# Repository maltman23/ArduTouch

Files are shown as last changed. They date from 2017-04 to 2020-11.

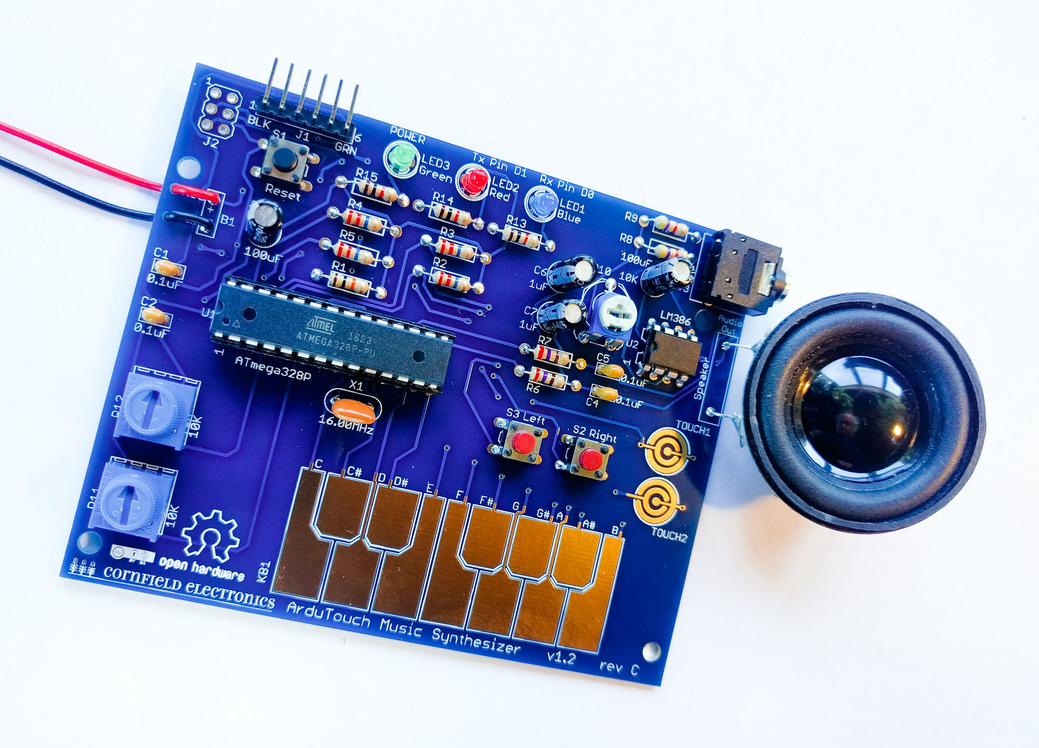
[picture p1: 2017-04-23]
Photo/ArduTouch.jpg

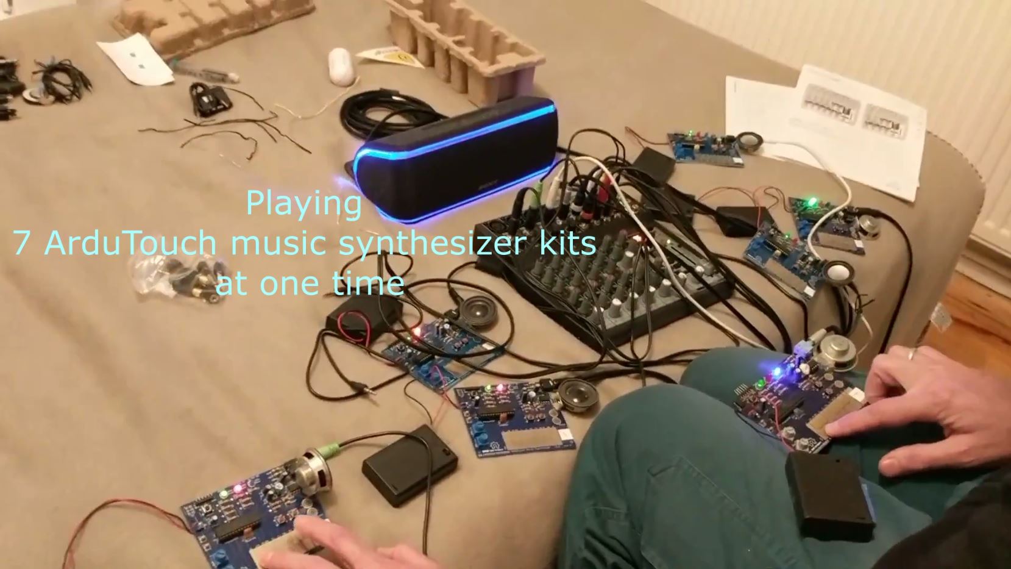
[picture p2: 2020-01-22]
Demo videos/7 at Once/7 ArduTouch at Once thumb.JPG

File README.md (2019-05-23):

# ArduTouch
photo of ArduTouch
ArduTouch is an Arduino-compatible music synthesizer kit.  
Build it, and it works!  
Way low cost (currently $30.)  
It comes with a pre-programmed music synthesizer that makes way cool sounds and music and noise.

An ArduTouch library is available for programming in more super nice synthesizer features, and for making your own synthesizers.
The library comes with examples (with more to come) that serve as a nice tutorial on how to create your own ArduTouch synthesizers (which are Arduino sketches).

ArduTouch is really just an Arduino Uno clone with a small amplifier & speaker, with a PCB touch keyboard, a couple of extra buttons, and a couple of pots (for playing music and controlling the sounds).  The ArduTouch Arduino Library is where the real magic comes from!

For those who want to learn more, the documentation teaches the basics of Digital Signal Processing for audio generation (more documentation coming soon).

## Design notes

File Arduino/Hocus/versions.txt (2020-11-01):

Versions:

   1.00  use embedded U/I frames 
         _Sn2345 not available if CONSOLE_OUTPUT
         syncs with library 1.16
   0.99  === FIRST PUBLISHED VERSION ===

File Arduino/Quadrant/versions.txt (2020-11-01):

Versions:

   1.73  use embedded U/I frames 
         syncs with library 1.16
   1.72  bugfix: upper bound condition in LED iteration corrected to "< NUMLEDs" from "<= NumLEDs"
         [31722] _STNDLONE_ lib 1.15 Build 1.6.6
   1.71  newOsc() returns NULL (instead of new Osc())
   1.70  nix BUILD_166 conditional compilation sections
   1.69  add FRAME21 pots to control lead 1 detune and transpose
         [31742] _STNDLONE_ BUILD_166
   1.68  edit presets/macros to use byte values <= 128 when setting LFO depths 
         syncs with library 1.13
         [31684] _STNDLONE_ BUILD_166
   1.67  === FIRST PUBLISHED VERSION ===

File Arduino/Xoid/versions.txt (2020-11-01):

Versions:

   0.98  use embedded U/I frames 
         syncs with library 1.16
   0.97  edit presets to use byte values <= 128 when setting LFO depths 
         syncs with library 1.13
   0.96  quiet preset loading
   0.95  resident Gain amplitude modifier is replaced by library's Gain effect
         syncs with 1.10
   0.94  Synth::setup() renamed ::config() to circumvent Arduino bug
         syncs with 1.10
   0.93  set_baud_rate() nixed
         normal blink rate
         syncs with 1.08
   0.92  === FIRST PUBLISHED VERSION ===

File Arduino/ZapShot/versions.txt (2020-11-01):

Versions:

   1.34  statusLED logic is rewritten
   1.33  ZapShotSynth::forEach() migrated to library as VoxSynth::forEach()
         syncs with library 1.15
   1.32  bugfix: autotrig LED must be refreshed on reset
   1.31  edit presets to use byte values <= 128 when setting LFO depths 
         syncs with library 1.13
   1.30  Synth::setup() renamed ::config() to circumvent Arduino bug
         syncs with 1.10
   1.29  === FIRST PUBLISHED VERSION ===

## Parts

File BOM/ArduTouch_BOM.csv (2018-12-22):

Qty | Designator | Description | Jameco | Mouser | mfg | mfg part # | mfg | mfg part #
1 | B1 | 3xAA battery holder w/ leads, w/ switch | 216144 | 854-PW3AA | Jameco | SBH-331-AS-R | BusBoard | PW-3AA
4 | C1, C2, C4, C5 | 0.1uF, 50V, ceramic, 0.1" spacing leads |  | 594-K104K15X7RF53L2 | Vishay / BC Components | K104K15X7RF53L2
2 | C3, C8 | 100uF, 16V or higher, electrolytic, radial, 0.1" spacing leads |  | 598-107CKS016M | Cornell Dubilier - CDE | 107CKS016M
2 | C6, C7 | 1uF, 16V or higher, electrolytic, radial, 0.1" spacing leads |  | 598-105CKR050M | Illinois Capacitor / CDE | 105CKR050M
1 | J1 | 1x6, right-angle (FTDI) |  | 649-68016-106HLF | FCI | 68016-106HLF
0 | J2 | not used
1 | J3 | headphone, stereo, 3.5mm, switched |  | 806-STX-31205B284C | Kycon | STX-3120-5B-284C
1 | LED1 | Blue LED, 5mm |  | 941-C5SMFBJFCR0U0351 | Cree | C5SMF-BJF-CR0U0351
1 | LED2 | Red LED, 5mm |  | 941-C5SMFRJFCT0W0BB1 | Cree | C5SMF-RJF-CT0W0BB1
1 | LED3 | Green LED, 5mm |  | 941-C5SMFGJFCV0Y0791 | Cree | C5SMF-GJF-CV0Y0791
1 | R1 | 10K, 1/4W, 5% | 691104 | 71CCF0710K0JKE36 | Jameco | CF1/4W103JRC | Vishay | CCF0710K0JKE36
4 | R2, R3, R4, R5 | 22M, 1/4W, 5% |  | 660-CF1/4C226J | KOA Speer | CF1/4C226J
2 | R6, R7 | 270, 1/4W, 5% | 690726 | 588-OD271JE | Jameco | CF1/4W271JRC | Ohmite | OD271JE
2 | R8, R9 | 4.7K, 1/4W, 5% | 691024 | 71-CCF07J4.7KE3 | Jameco | CF1/4W472JRC | Vishay | CCF074K70JKE36
1 | R10 | 10K trim pot (screwdriver adjust - Volume) |  | 652-3319P-1-103 | Bourns | 3319P-1-103
2 | R11, R12 | 10K trim pot (knob adjust) |  | 858-72PTR10KLF | BI Technologies / TT Electronics | 72PTR10KLF
3 | R13, R14, R15 | 1K, 1/4W, 5% | 690865 | 71-CCF071K00JKE36 | Jameco | CF1/4W102JRC | Vishay | CCF071K00JKE36
1 | S1 | SPST tact switch, 4-pin, Black button (Reset) |  | 688-SKHHAK | ALPS | SKHHAKA010
2 | S2, S3 | SPST tact switch, 4-pin, Red button |  | 688-SKHHAQ | ALPS | SKHHAQA010
1 | SPKR1 | 40mm diameter speaker, 3W, 4 Ohm |  | 665-AS04004PR-R | PUI Audio | AS04004PR-R
1 | U1 | ATmega328P-PU |  | 556-ATMEGA328P-PU | Atmel | ATMEGA328P-PU
1 | U2 | NJM386BD |  | 513-NJM386BD | NJR | NJM386BD
1 | X1 | 16.0MHz ceramic resonator |  | 81-CSTLS16M0X55Z-A0 | Murata Electronics | CSTLS16M0X55Z-A0
1 | PCB | PCB
1 | U1 socket | 28-pin DIP socket | 112299 | 81CSTLS16M0X55ZA0 | Jameco | 6000-28NDW | TE Connectivity | 1-2199298-9
0 | U2 socket | not used (U2 is soldered directly to PCB)
1 | small bag | 7x10cm reclosable plastic bag |  |  | Aliexpress
1 | large bag | 15x22cm reclosable plastic bag |  |  | Aliexpress
1 | label

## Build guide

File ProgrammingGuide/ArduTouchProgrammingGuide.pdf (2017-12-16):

# ArduTouch Music Synthesizer

## Programming Guide

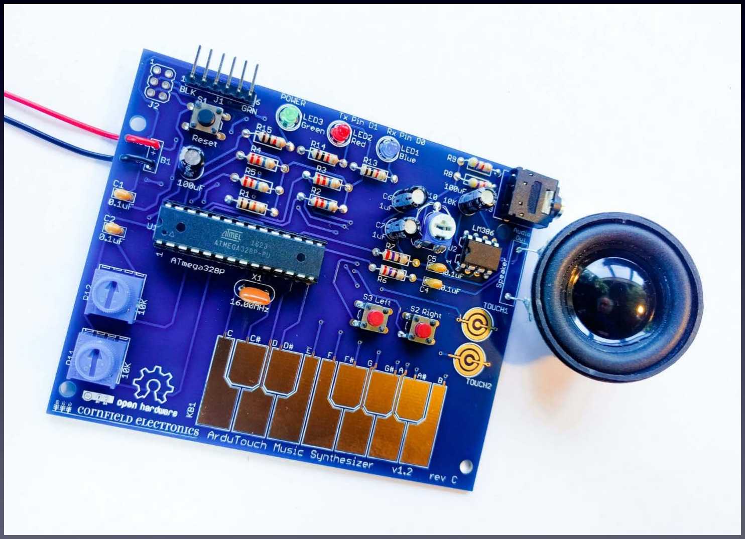
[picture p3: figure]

## rev C

15-Dec-2017

# Let’s make noise!

Your ArduTouch comes pre-programmed with a really cool synthesizer, called “Thick”.

“Thick” plays 4 sawtooth waves at once.
- the left and right buttons change octaves
- long press the left and right buttons to change sounds
- the Bottom knob controls the glide rate
- the Top knob controls how each of the 4 notes glide separately
- Try playing with these and see!

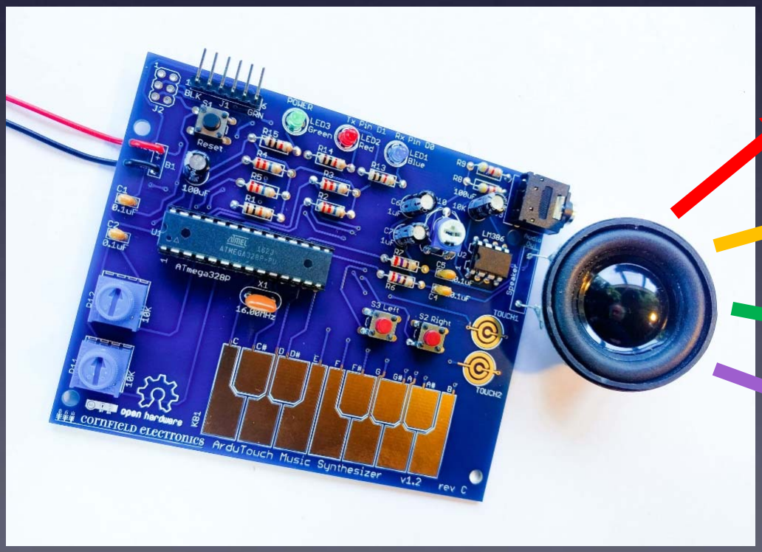
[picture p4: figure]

# Let’s make noise!

Your ArduTouch comes pre-programmed with a really cool synthesizer, called “Thick”.

If you are happy playing with “Thick” then no need to re-program your ArduTouch.

But if you want to
program other synths into your ArduTouch,
the next pages show you how…

# Re-programming the ArduTouch

We have written several way cool synthesizers for ArduTouch! Each is unique, and each way different than the others.

To program in a new synth in your ArduTouch, you will need:
- the Arduino software <http://arduino.cc>
- a USB-Serial adapter cable (such as an FTDI, or equivalent)
- a synth sketch and the ArduTouch Arduino library <http://cornfieldelectronics.com/cfe/projects.php#ardutouch>

# Arduino

Arduino is a very powerful tool! But it is very easy to use. It was designed for total beginners to use successfully.

I won’t give a complete tutorial here – just some basics.
For more info, there are many good Arduino tutorials online. A good place to start is:
<https://www.arduino.cc/en/Tutorial/HomePage>

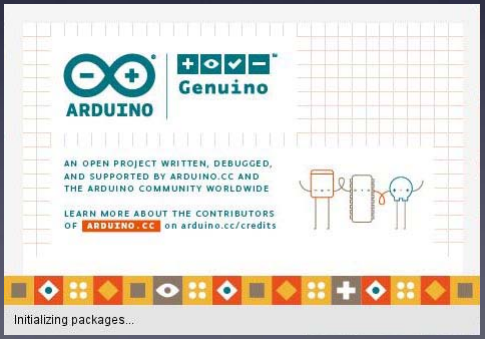
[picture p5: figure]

# Arduino

First:
Download and install the Arduino software < http://arduino.cc >

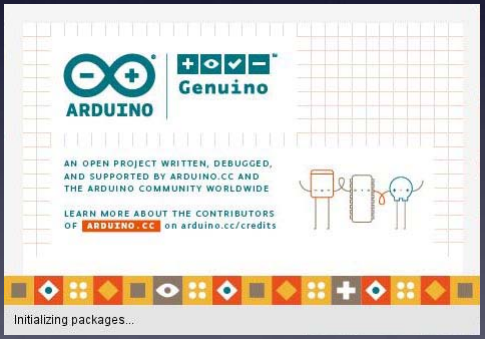
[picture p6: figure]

# Re-programming the ArduTouch

Second:
Download and install the ArduTouch Arduino library <http://cornfieldelectronics.com/cfe/projects.php#ardutouch>

Instructions for installing a .zip library are at: < https://www.arduino.cc/en/Guide/Libraries>
Scroll down till you see the section: “Importing a .zip Library“

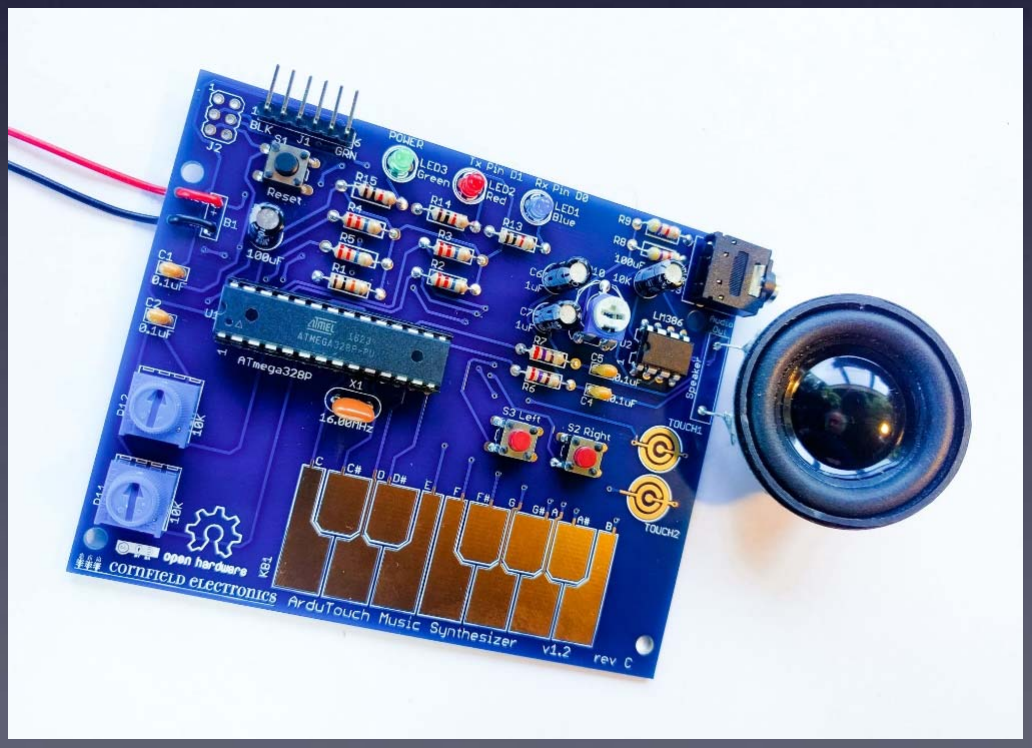
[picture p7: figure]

# Re-programming the ArduTouch

Third:
Download ArduTouch synth sketches <http://cornfieldelectronics.com/cfe/projects.php#ardutouch>

Store them on your computer anywhere you like.

Ones I have available look something like this:

# Connecting your ArduTouch to your computer

USB-Serial adapter cable

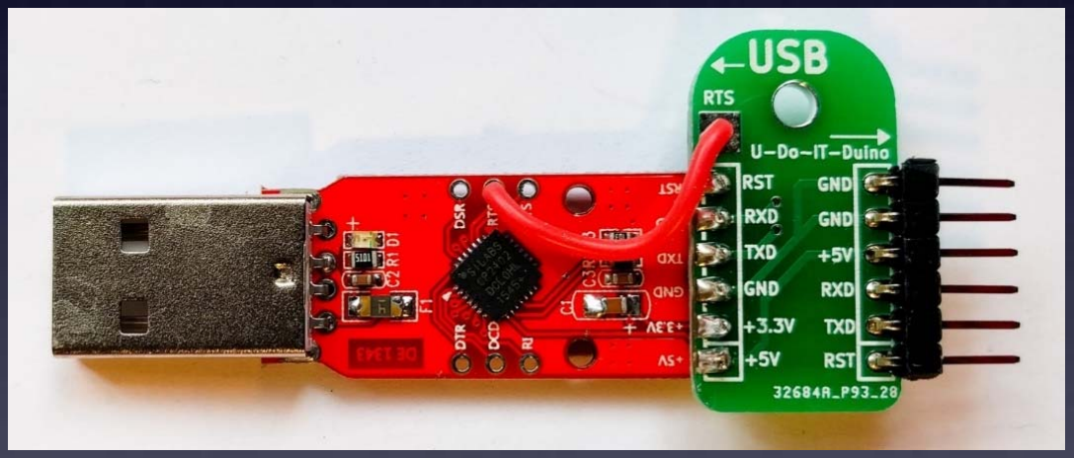
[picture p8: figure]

# Connecting your ArduTouch to your computer

USB-Serial adapter cable

Ones I have available look something like this:

You will need to download and install a driver
for your Operating System (Windows, MacOS, or Linux):

<https://www.silabs.com/products/development-tools/software/usb-to-uart-bridge-vcp-drivers>

# Connecting your ArduTouch to your computer

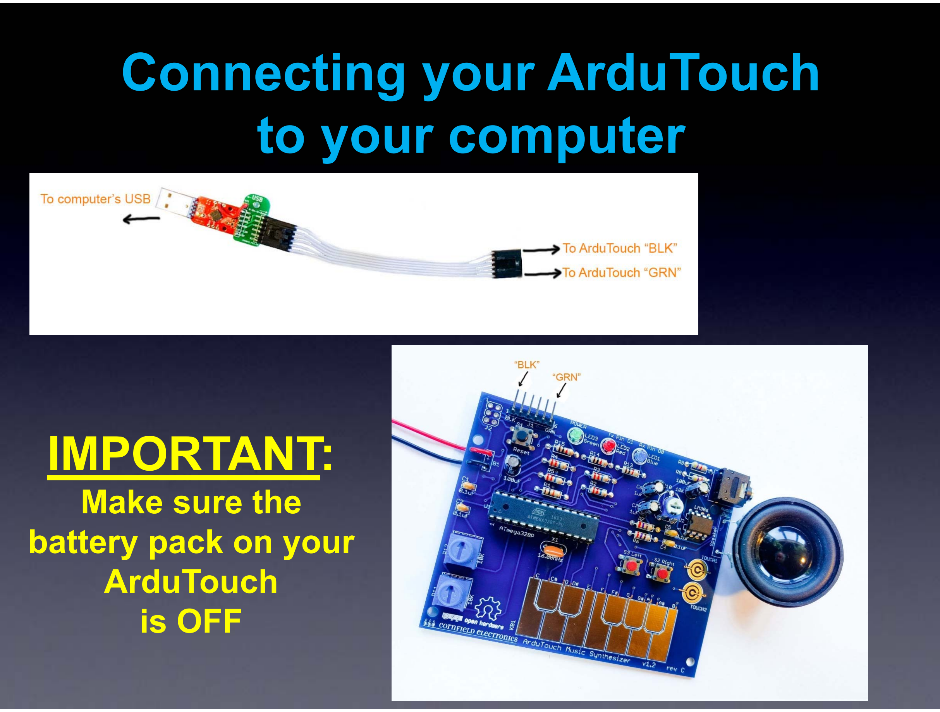
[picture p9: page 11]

# IMPORTANT:

## Make sure the battery pack on your ArduTouch is OFF

# Arduino

After you download and install the Arduino software start it, and you will see a screen that looks like this:

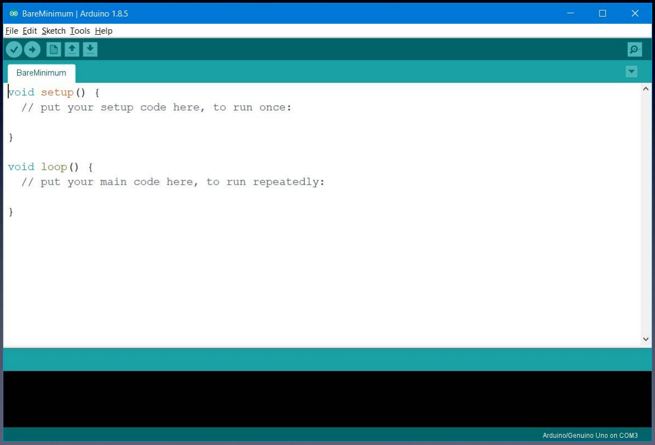
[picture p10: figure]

# Arduino

The first time you start your Arduino software you need to do two things to set things up

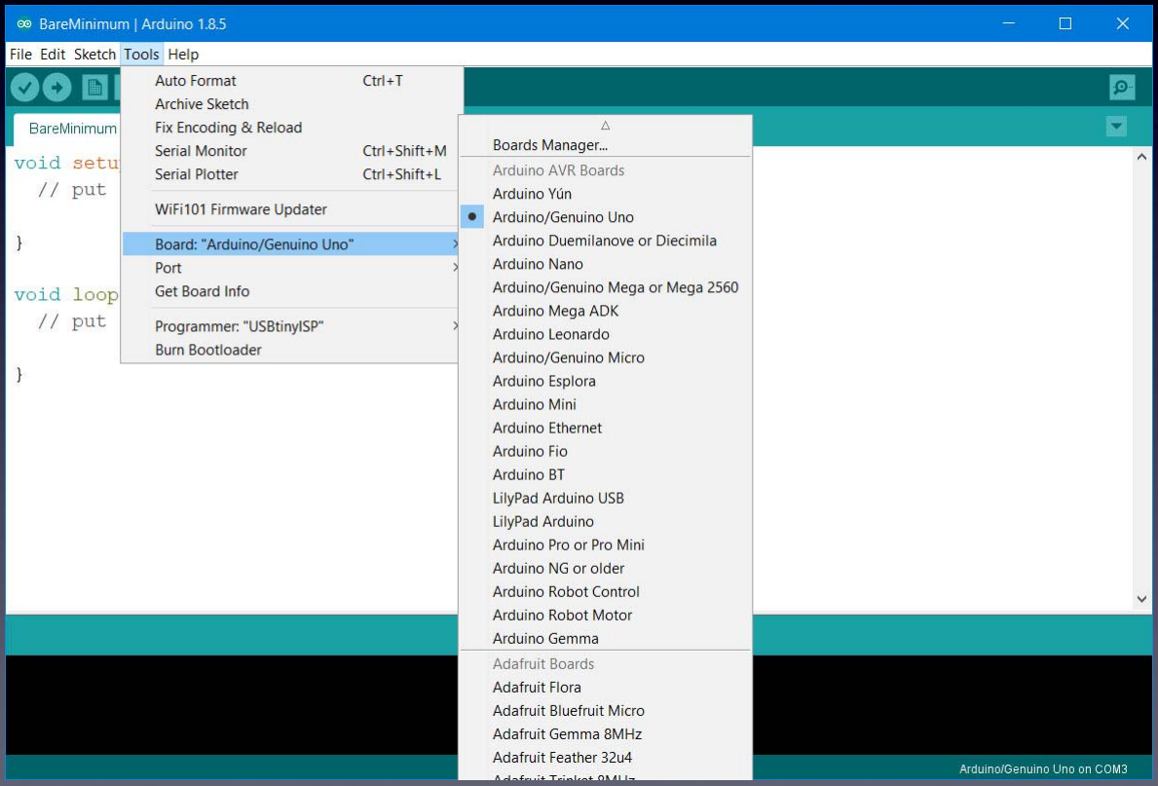
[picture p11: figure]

(1)
Choose “Uno”
as the Board

(Your
ArduTouch board
acts
just like
an
Arduino Uno board)

# Arduino

The first time you start your Arduino software you need to do two things to set things up

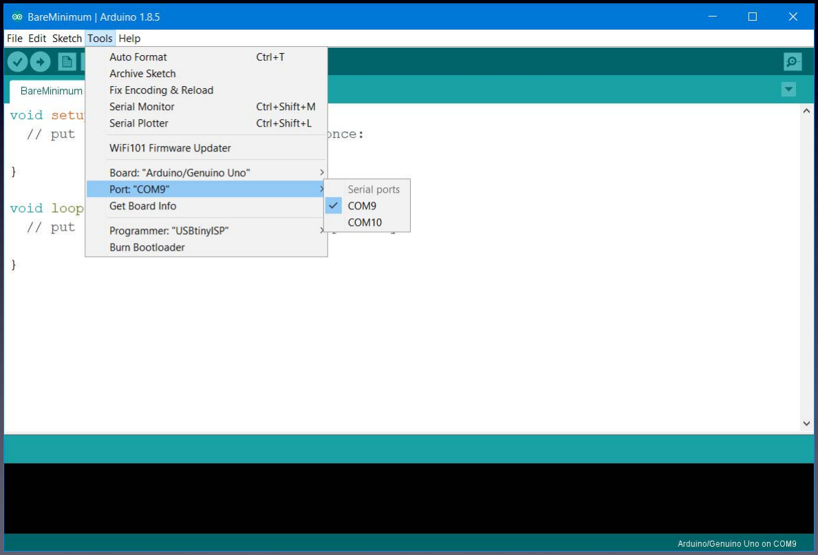
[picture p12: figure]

(2)
Choose
the Port
(this will be
different
depending on
your Operating
System)

(After installing
the driver
for your USB-Serial
cable
your operating system
will see a serial port
and it appears here.)

# Arduino

Your Arduino software is now ready to program your ArduTouch!

# Arduino

You can open an ArduTouch synth sketch from: File → Open…
(I opened “Arpology here)

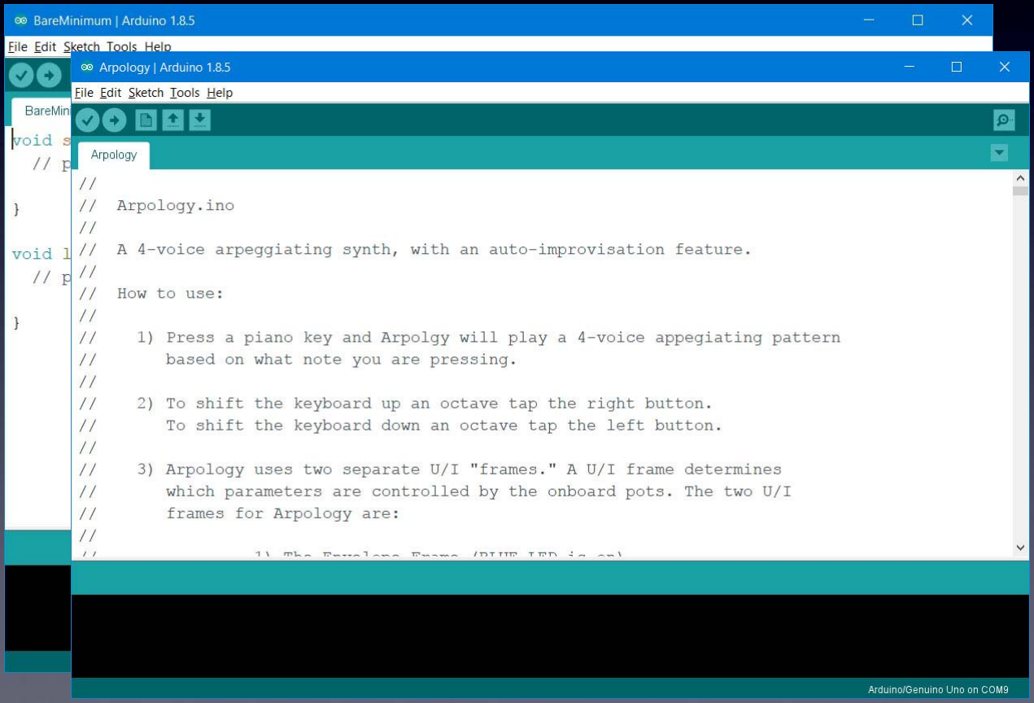
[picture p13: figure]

# Arduino

With the USB-Serial cable connected to your ArduTouch board press the Upload button

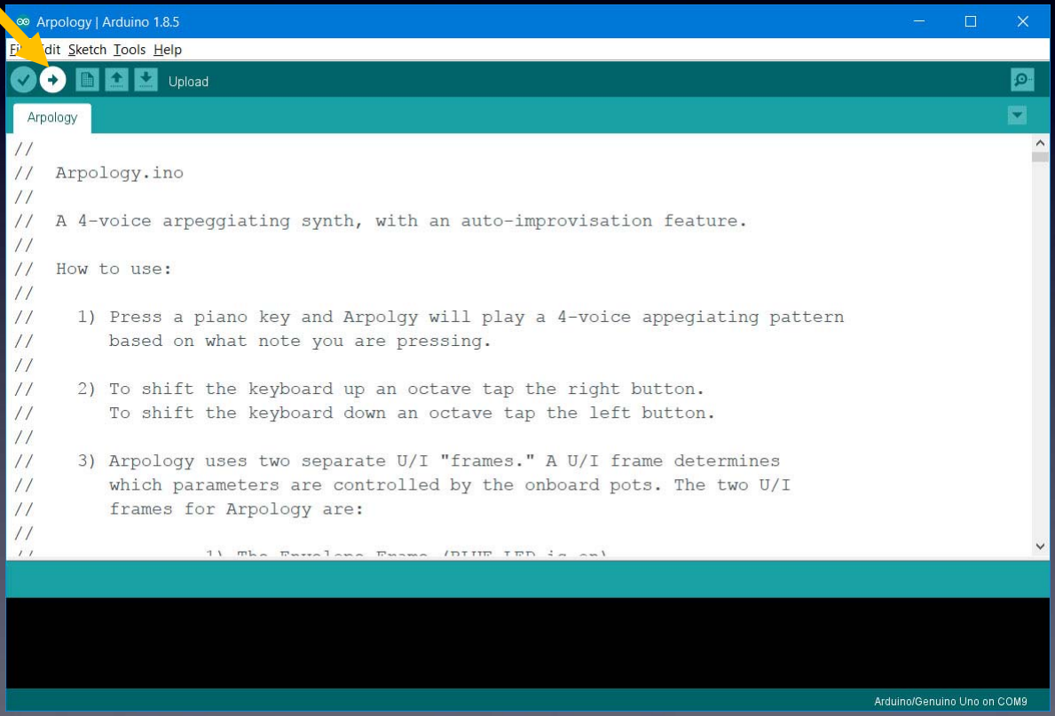
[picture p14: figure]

# Arduino

While uploading, you will see a progress bar…

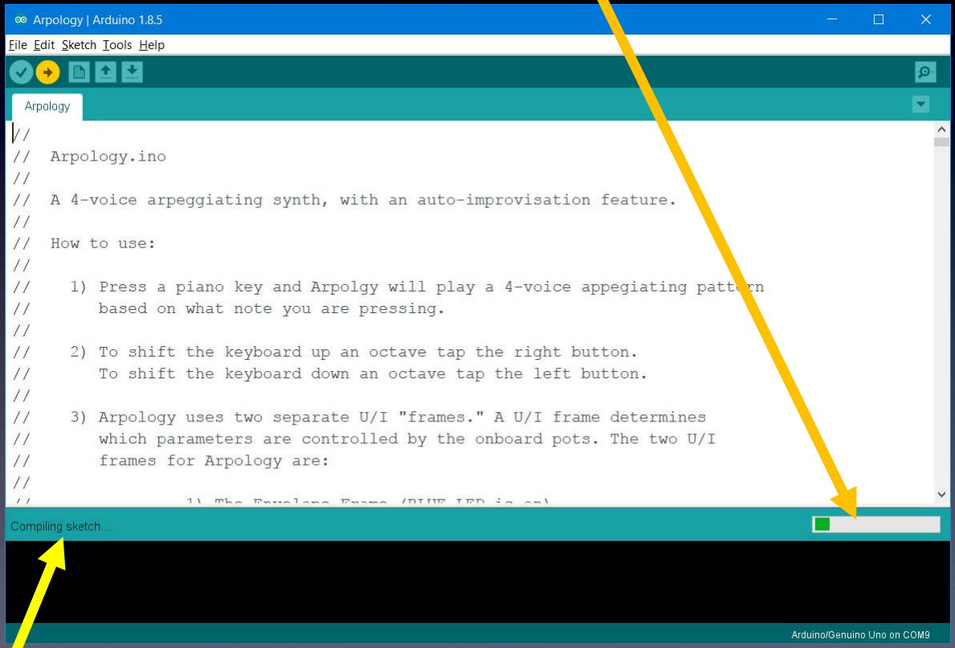
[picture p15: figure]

…and when it’s completed successfully, it says: “Upload done”

# ArduTouch

Disconnect your ArduTouch board from the USB-Serial cable,

# And…

turn on your battery pack,

# Let’s make new noise!

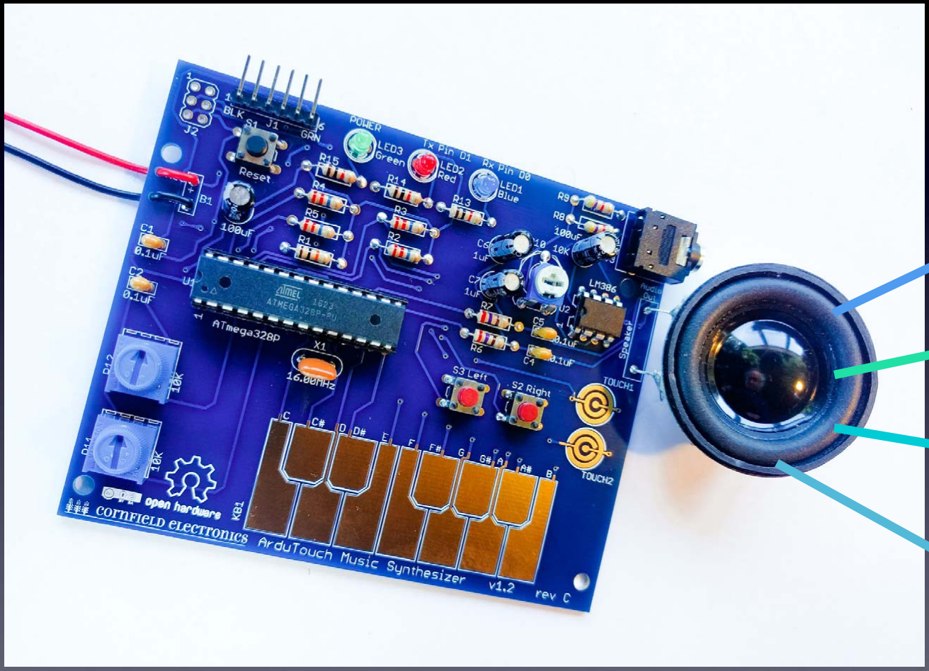
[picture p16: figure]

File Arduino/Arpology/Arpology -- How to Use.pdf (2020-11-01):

## Arpology

A 4‐voice arpeggiating synth, with an auto‐improvisation feature. With a nod to musical heroes Brian Eno and J.S. Bach.

How to use:

1) Press a piano key and Arpolgy will play a 4-voice appegiating pattern based on what note you are pressing.
2) To shift the keyboard up an octave Tap the right button.
To shift the keyboard down an octave Tap the left button.
3) Arpology uses two separate User Interface (U/I) "frames." A U/I frame determines which parameters are controlled by the onboard pots. The two U/I frames for Arpology are:
1) The Envelope Frame (BLUE LED is on)

Top Pot controls envelope attack Bottom Pot controls envelope decay/sustain.

2) The Arpeggiator Frame (RED LED is on)

Top Pot selects arpeggiation pattern. Bottom Pot controls arpeggiation rate.

4) To switch between U/I frames, Press the left or right buttons. Pressing the right button selects the Envelope Frame.
Pressing the left button selects the Arpeggiator Frame.
5) To activate the automatic improvisor Double-Tap the left button. Arpology now "plays itself" (and never repeats!) using Bach-like modulation. The LED for the current frame will begin flashing, indicating that the auto-improvisor is on. While the auto-improvisor is on, Arpology will not respond to key presses, but it will respond to adjustments to the two knobs (and you can also control if the two knobs control envelope or arpeggio). To turn off the auto-improviser Double-Tap the left button again.

Note: A list of all types of button presses this synth uses, including “Tap”, “Press” and “Double-Tapping” can be seen on page 2 of this document.

6) There are 10 presets for Arpology. These can be selected by Double-Tapping the right button and then pressing one of the following piano keys:

C (0) - turn off all vibrato and panning effects
C# (1) - add vibrato to high voices
D (2) - use a slow panning effect
D# (3) - use a medium-speed panning effect
E (4) - use a fast panning effect
F (5) - play "Ambia", a slow moving improv F# (6) - use a major tonality
G (7) - play "Streaker", a fast moving improv G# (8) - use a minor tonality
A (9) - reset Arpology to its initial state

Types of button presses:

Tap: | quickly tap a button
Press: | long‐press a button
Double‐Tap: quickly double‐tap a button

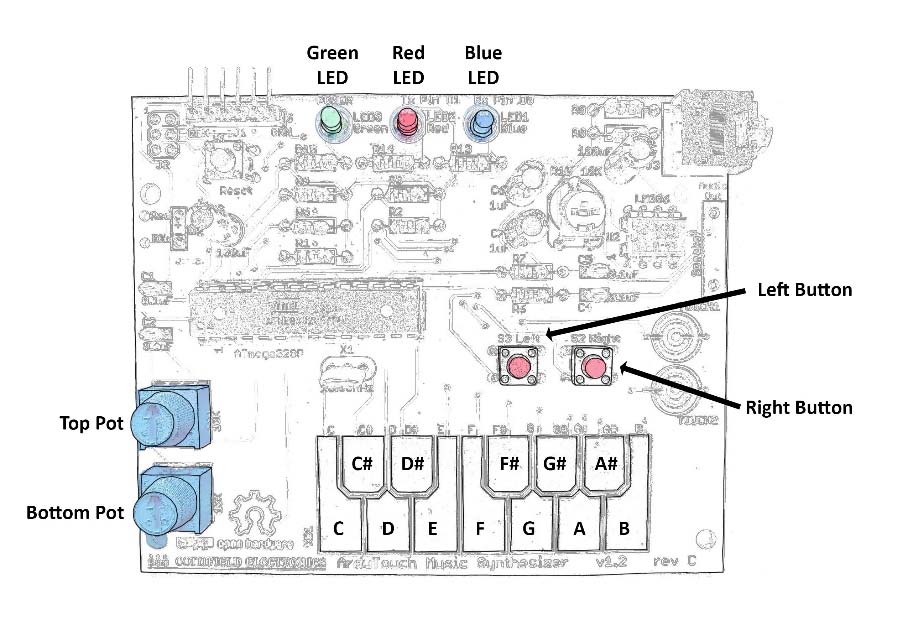
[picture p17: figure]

Programming Notes:

1) Arpology is meant to be compiled using the "Stand-alone" runtime model. Otherwise, the LEDs will not operate. This runtime model can be set by uncommenting the "#define __STNDLONE__" statement in Model.h of the ArduTouch library.

Copyright (C) 2020, Cornfield Electronics, Inc.

This work is licensed under the Creative Commons Attribution-ShareAlike 4.0
Unported License.

To view a copy of this license, visit http://creativecommons.org/licenses/by-sa/4.0/

Created by Bill Alessi & Mitch Altman.

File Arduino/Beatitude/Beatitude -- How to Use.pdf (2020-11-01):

## Beatitude

A Drum and Bass synth with real‐time drum sequencer for the ArduTouch.

How to use:

------------ | Playing Drums | ------------

Play the keys on the keyboard. Different drums will sound depending on the note played, as shown in the diagram below:

K = Kick Drum, T = Tom, S = Snare, R = RimShot, H = High Hat

| | | K | | | T | | | | | S | | | R | | | H | | |
| | ___ | ___ | | | ___ | ___ | ___ | |
| K | | K | | T | S | | S | | | R | | H |

----------- | Recording a Drum Sequence | ------------

To record a drum sequence Press the right button.

The blue LED will turn on, and a "click track" (metronome) will start.

Note: Please see page 4 of this document to see the types of button presses used on this synthesizer, including “Press” and “Double-Tap”.

When the blue LED is on, but not blinking, it means that the ArduTouch is playing a "cue measure". This is a single measure which plays before the actual recording starts, and lets you get ready for your performance.
Any notes you attempt to play during the cue measure will not sound, and will not be recorded.

By default there are 4 beats in a measure.

When the cue measure ends the blue LED will start flashing. This means that the ArduTouch is now recording anything you play (but it doesn’t blink in time to the beat). By default the sequence is 4 measures long, after which the blue LED will turn off.

----------- | Playing back a Drum Sequence | ------------

To play back your drum sequence Press the left button.

The red LED will start blinking (but it doesn’t blink in time to the beat), and your sequence will begin playing.

When the sequence reaches its end it will loop back to the beginning and continue to play (forever) until you Press the left button again.

While the drum sequence plays, you can play bass on top it by pressing keys on the touch keyboard (see below).

Note: If you don’t record your own drum sequence then playing a drum sequence will play the nice pre-recorded sequence that comes with Beatitude.

------------ | Playing Bass | ------------

When a drum sequence is playing back, the ArduTouch keyboard will turn into a bass instrument, and you can play bass along with the recorded drums. The octave setting for the bass can be bumped up and down by Tapping the right and left buttons respectively.

To revert to playing drums, stop the sequence (by Pressing the left button).

----------- | Controlling the Tempo | -----------

Rotate the bottom pot to slow down or speed up the tempo.

----------- | Panning between drums and bass | -----------

The top pot controls the balance between the drum kit and the bass.

------- | Setting Beats per Measure & # of Measures | --------

To change the # of beats per measure, and the # of measures in a sequence, Tap-Press the left button (think of this as a "Double-Tap" but with the second tap being of a longer duration.)

The red LED will turn on, indicating that the ArduTouch keyboard is now in "Menu" mode.

Select the # beats per measure by pressing a key:

| | | 2 | | | 4 | | | | | 7 | | | 9 | | | 1 | | |
| | | | | | | | | | | | | | | | | | | | | 1 | | |
| | ___ | ___ | | | ___ | ___ | ___ | |
| 1 | | 3 | | 5 | 6 | | 8 | | | 10 | 12 |

Now select the # of measures by pressing a second key:

| | | 2 | | | 4 | | | | | 7 | | | 9 | | | 1 | | |
| | | | | | | | | | | | | | | | | | | | | 2 | | |
| | ___ | ___ | | | ___ | ___ | ___ | |
| 1 | | 3 | | 5 | 6 | | 8 | | | 10 | 16 |

The red LED will now turn off.

Types of button presses:

Tap: | quickly tap a button
Press: | long‐press a button
Double‐Tap: quickly double‐tap a button
Tap‐Press: | think of this as a Double‐Tap but with the second tap being of a longer
| duration.


Copyright (C) 2020, Cornfield Electronics, Inc.

This work is licensed under the Creative Commons Attribution-ShareAlike 4.0
Unported License.

To view a copy of this license, visit http://creativecommons.org/licenses/by-sa/4.0/

Created by Bill Alessi & Mitch Altman.

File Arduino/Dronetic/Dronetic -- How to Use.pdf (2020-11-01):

## Dronetic

A droning synth using massed quantum square wave oscillators.
Includes many presets, for beautiful, spacey, or noisy drones, on top of which you can play your own melodies

How to use (quick):

-------- Presets --------

Double-Tap the left button and the drone voices will begin. Then you can play a melody on top of the drone by pressing keys on the touch-keyboard.

There are lots of way cool presets! Some are beautiful and spacey, some are noisy. Explore!

A list of all Presets can be seen on page 6 of this document.

Load preset sounds by Double-Tapping the right button and then pressing any "white" key.

Note: A list of all types of button presses this synth uses, including “Double-Tapping” can be seen on page 8 of this document.

Once you choose a preset, play notes on the keyboard and twiddle the knobs while playing and explore the music you can create!

If you want to have more control over lots of nice, warm, dark, or noisy sounds available with the Dronetic synth, the following pages will explain how.

==== Audio Flow Diagram for the Dronetic Synth ====

| Drone 0 | ---> | Stereo Panner | <--- | Drone 1 |
v | v
[left audio] <--- | Mixer | ---> [right audio]
| ----------- ^ | | ---------------- | Lead Voice | ----------------

==== Diagram of the Drone Voice ====

| Oscillator Section | --> AutoWah --> Gain --> [output]

==== Diagram of the Drone Oscillator Section ====

| -->| Osc 0 | | all oscillators are |
| | --------- | square waves with | |
| | | integral periods. | |
| -->| Osc 1 | | each osc can be | |
notes | | --------- | switched on or off. | | -----> [output]
-----> | | | | | |
route | | --------- | output is combined. |
to | | -->| Osc 2 | | |
current | | --------- | ---------------
Osc | | | | | Transpose | # semi-tones to transpose note
| -->| Osc 3 | | | | Freeze | | ignore note input
| | | | Pulse Width | set pulse width for all osc
select current Osc (follows note input, with transposition, unless Freeze)

==== Diagram of the Lead Voice ====

Lead Voice comes in two varieties, Ambient and Caustic

Ambient | | | Caustic
| WaveOsc | --> [output] | | | PureSquare | ----> | | |
----------- | | -------------- | ^ | | | |
^ | | | freq | | | | |
| | | | diff | | | XOR | --> [output]
"Ether" | | ----------- | v | | | |
Wavetable | | | WaveOsc | -------> | | |
| | ^ | -------
| | "Ether"
| | Wavetable
Ambient is default voice | | | Caustic is used in 2 presets

Interaction between Lead Voice and Drones

When a note is played by the lead voice, that note is also routed to each drone. The drone will then either ignore the note (because Freeze is enabled -- see diagram for Drone Oscillator Section above) or it will play the note (transposed by the number of semi-tones specified by Transpose) using its currently selected oscillator.

Each preset pre-determines whether note input is frozen, and what the selected oscillator is for each drone. The value of Transpose can be changed via the onboard pots. See below for more details.

### How to use (more in-depth):

Double-Tap the left button and the drone voices will begin.
Double-Tap the left button again and the drone voices will stop.

So, double-Tapping the left button toggles the drone voices on and off.

When the drone voices are off you can also start them by touching any keyboard key (which will also be played as a note in the lead voice).

Once the drone voices have started, notes that you play on the keyboard
will control the lead voice (and perhaps the current osc in each drone).

To raise the lead voice by an octave, Tap the right button once.
To lower the lead voice by an octave, Tap the left button once.

Each LED can be in one of 3 states : OFF - ON - BLINKING

The LEDs indicate what parameters the pots control:

red LED | blue LED | top POT | bot POT
OFF | OFF | autowah 0 FREQ | autowah 0 DEPTH
ON | OFF | autowah 1 FREQ | autowah 1 DEPTH
BLINK | OFF | panning FREQ | panning DEPTH
OFF | ON | autowah 0 CUTOFF | autowah 1 CUTOFF
ON | ON | drone 0 PULSE WIDTH | drone 1 PULSE WIDTH
BLINK | ON | drone 0 TRANSPOSE* | drone 1 TRANSPOSE**
OFF | BLINK | lead ATTACK | lead DECAY
ON | BLINK | lead SUSTAIN | lead RELEASE
BLINK | BLINK | XOR FREQ DIFF*** | lead PORTAMENTO

To bump the red LED state: Press left button
To bump the blue LED state: Press right button

So, by Pressing the left and right buttons you can change what parameters are controlled by the pots.

* current osc only, effective on presets: Eire, Oslo
** current osc only, effective on presets: Borea, Crystal, Eire, Faroe, Oslo *** effective on presets: Cerebus Riven

==== Guide to Dronetic's Presets ====

Load presets by Double-Tapping the right button and then Pressing any "white" key. Once a preset is loaded, the drone voices for that preset will begin to play.

The presets are as follows:

Key | Name | Performance Notes
C | Borea | ambient. play in E minor / A
D | Crystal | ambient. play in D minor / Bb major
E | Eire | ambient. play in C major
A | Faroe | ambient. play in D major
G | Oslo | ambient. play in C major
A | Riven | caustic. hold notes then slide finger for pitch bend
B | Cerebus | caustic.

----------------------------------------------------------------------About Dronetic's Tuning

When you start playing notes on the keyboard you will probably notice that the 'C' key plays an 'F'. And if you have a really good ear you may also notice that the interval between C# and G# is not exactly a 5th.

Why is this?

To explain the 2nd observation first, Dronetic uses Harmonic Tuning (also known as Just Temperament or "Helmholtz's scale") instead of the usual Equal Temperament (which is the system default).

Harmonic Tuning is actually more "natural" than Equal Temperament (which was created as a compromise so that keyboard instruments could play in all keys). In Harmonic Tuning the relative frequencies of all notes compared to the tonic ('C' in our case) are rational numbers:

Unison | 1/1
Minor Second 25/24
Major Second | 9/8
Minor Third | 6/5
Major Third | 5/4
Fourth | 4/3
Diminish 5th 45/32
Fifth | 3/2
Minor Sixth | 8/5
Major Sixth | 5/3
Minor Seventh 9/5
Major Seventh 15/8
Octave | 2/1

Dronetic uses quantum square wave oscillators which can only be set to frequencies which have integral wavelengths. The frequencies produced by these oscillators conform more closely to a scale in Harmonic Tuning than one in Equal Temperament.

But why does the 'C' key play an 'F'?

The short answer is that on the ArduTouch, whose audio rate is ~15.6 kHz, 'F' (in octave 1) has a period of 360 samples. 360 is a number favored by the ancients because it is divisible by a large number of integers: 1, 2, 3, 4, 5, 6, 8, 9, 10, 12, 15, 18, 20, 24, etc. It so happens that by using a tonic frequency whose period is 360, we are able to use quantum oscillators to closely approximate the Harmonic Tuning scale over several octaves. Low 'F', so to speak, is the natural tonic frequency of the ArduTouch.*

*actually, on the ArduTouch a waveform with a period of 360 samples generates a tone with a frequency of 43.578 Hz. In the equal temperament scale, 'F' in octave 1 has a frequency of 43.654 Hz.

Types of button presses:

Tap: | quickly tap a button
Press: | long-press a button
Double-Tap: quickly double-tap a button


Copyright (C) 2020, Cornfield Electronics, Inc.

This work is licensed under the Creative Commons Attribution-ShareAlike 4.0
Unported License.

To view a copy of this license, visit http://creativecommons.org/licenses/by-sa/4.0/

Created by Bill Alessi & Mitch Altman.

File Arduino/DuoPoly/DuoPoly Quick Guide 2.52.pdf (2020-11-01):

# DuoPoly

# Quick Operation Guide

# Version 2.52

# Cornfield Electronics

# Intro

DuoPoloy is a polyphonic music synthesizer that can be played with the ArduTouch board’s touch-keyboard. It has 8 octaves, Tremelo, Vibrato, distortion effects, Low Pass Filter, and several interesting waveform voices. It can also be used as a sequencer. As well as the touch-keyboard, DuoPoly makes use of the two knobs and two buttons on the ArduTouch board.

DuoPoly was the first synth created for the ArduTouch music synthesizer project. DuoPoly can be played as a synth, but its main intent was a synth to demonstrate and show off the sounds and features of the project and the ArduTouch Arduino library functions.

It can be played alone, but it can be more easily controlled (and understood) if you use the Arduino Serial Monitor (or, even better, another serial Terminal program).

The pages that follow comprise a reference guide for all of the features of DuoPoly.

Please see the last page of this document for an explanation of the types of button presses used on this synthesizer, including “Tap”, “Double-Tap”, “Tap-Press”, etc.

## main>

r | right voice
l | left voice
k | push console's virtual keyboard
p | select preset (0, 1, 2, 3, 4)
v | set volume (0 to 255)
w | select waveform (0, 1, 2*)
* | latch oscillator frequencies (geometric)
+ | latch oscillator frequencies (arithmetic)
u | unlatch oscillator frequencies
x | set transposition amount (in semi-tones)
[ | start sequencers
] | stop sequencers
| | pause/resume sequencers
. | mute
< | unmute
! | reset
? | display info
ESC or ` | exit sketch

* waveform 2 available only for __STNDLONE__ and __BAREBONE runtime models

(continued ...)

## main

| left button | | right button
Press | left voice | Press | right voice
Tap | Tap
Double-Tap exit sketch | Double-Tap

## volume

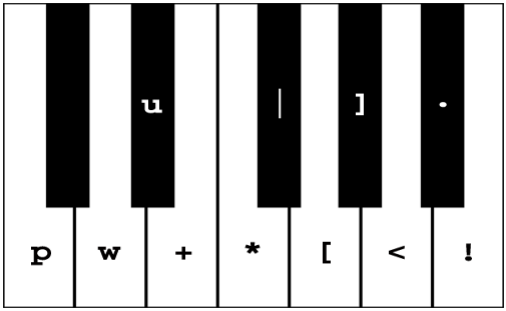
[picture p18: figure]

## right> or left>

d | detune oscillator (-128 to 127, total range is a quarter tone )
e | push envelope control
E push effects chain
f | set oscillator frequency (20.0 to 20000.0)
g | set glide speed (0 to 255, 0 = off)
k | push console's virtual keyboard
S push sequencer
t set sequencer tempo (15.0 to 20000.0) T push tremolo control
V push vibrato control
v | set volume (0 to 255)
w | select waveform (0, 1, 2*)
* | latch frequency geometrically
+ | latch frequency arithmetically
[ | start sequencer
] | stop sequencer
| | pause/resume sequencer
. | mute
< | unmute
! | reset
? | display info
ESC or ` | return to main panel

* waveform 2 available only for __STNDLONE__ and __BAREBONE__ runtime models

(continued ...)

## right or left

left button | right button
Press | Press | scroll pots
Tap - 1 octave | Tap + 1 octave
Double-Tap return to main panel | Double-Tap run key menu once
Tap-Press | Tap-Press program a sequence

## volume detune glide

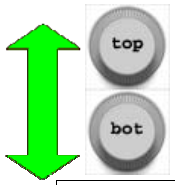
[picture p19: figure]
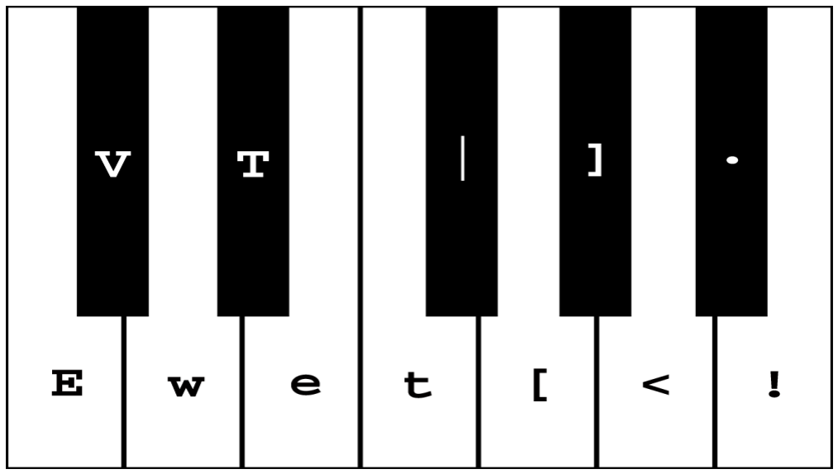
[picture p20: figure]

## Sqnc>

r | record a sequence (push step programmer)
t | set sequencer tempo (15.0 to 20000.0)
[ | start sequencer
] | stop sequencer
| | pause/resume sequencer
! | reset
? | display info

## step>

SPACE or . | ++duration
z | C
s | C#
x | D
d | D#
c | E
v | F
g | F#
b | G
h | G#
n | A
j | A#
m | B
, | high C
0 thru 8 | select octave 0 thru 8
? | display current octave
ESC or ` | commit sequence
left button | right button
Press | Press | ++duration
Tap - 1 octave | Tap + 1 octave
Double-Tap commit sequence | Double-Tap

## envelope>

a | set attack time (0 to 255)
d | set decay time (0 to 255)
r | set release time (0 to 255, 0 = hold)
s | set sustain level (0 to 255)
~ | set legato retriggering
' | set staccato retriggering
. | mute
< | unmute
! | reset
? | display envelope state
ESC or ` | exit envelope panel

(continued ...)

## envelope

left button | right button
Press | Press scroll pots
Tap | -1 octave | Tap | +1 octave
Double-Tap | exit envelope panel | Double-Tap | run key menu once

## attack decay sustain release

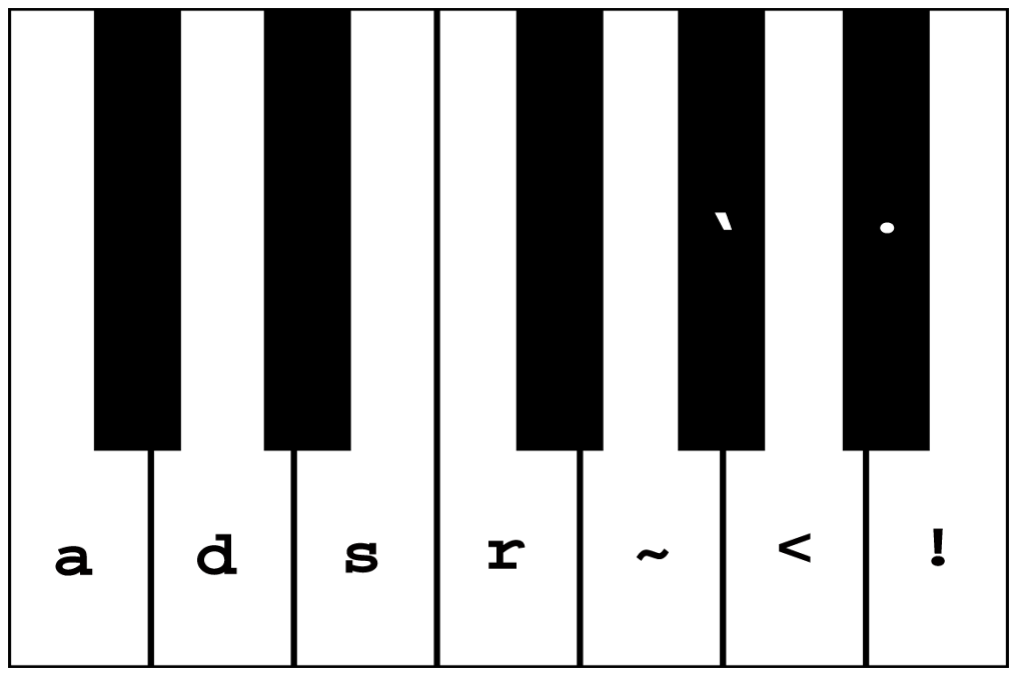
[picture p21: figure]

## tremolo>

f | set tremolo frequency (0.01 to 20.0)
d | set tremolo depth (0.0 to 1.0)
t | set trigger count (# half-cycles to traverse: 0-255)
~ | set legato retriggering
' | set staccato retriggering
+ | trigger starts af “softest” level, and increases
- trigger starts at “loudest” level, and decreases
. | mute
< | unmute
! | reset
? | display tremolo state
ESC or ` | exit tremolo panel

(continued ...)

## tremolo

left button | right button
Press | Press
Tap | -1 octave | Tap | +1 octave
Double-Tap | exit tremolo panel | Double-Tap | run key menu once

## frequency depth

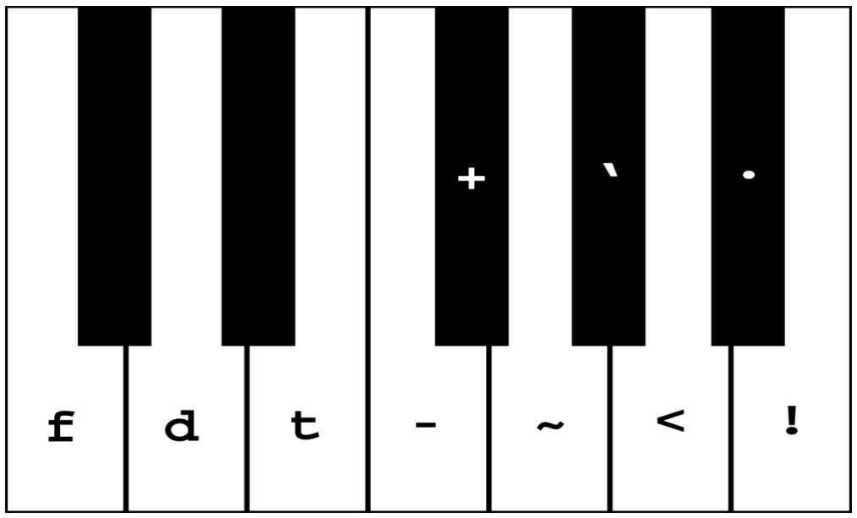
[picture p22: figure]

## vibrato>

f | set vibrato frequency (0.01 to 20.0)
d | set vibrato depth (0.0 to 1.0)
t | set fade time (in 1/8ths of sec: 0-255)
~ | set legato retriggering
' | set staccato retriggering
+ | set positive polarity (“fade in”)
- set negative polarity (“fade out”)
. | mute
< | unmute
! | reset
? | display vibrato state
ESC or ` | exit vibrato panel

(continued ...)

## vibrato

left button | right button
Press | Press
Tap -1 octave | Tap +1 octave
Double-Tap exit vibrato panel | Double-Tap run key menu once

## frequency depth

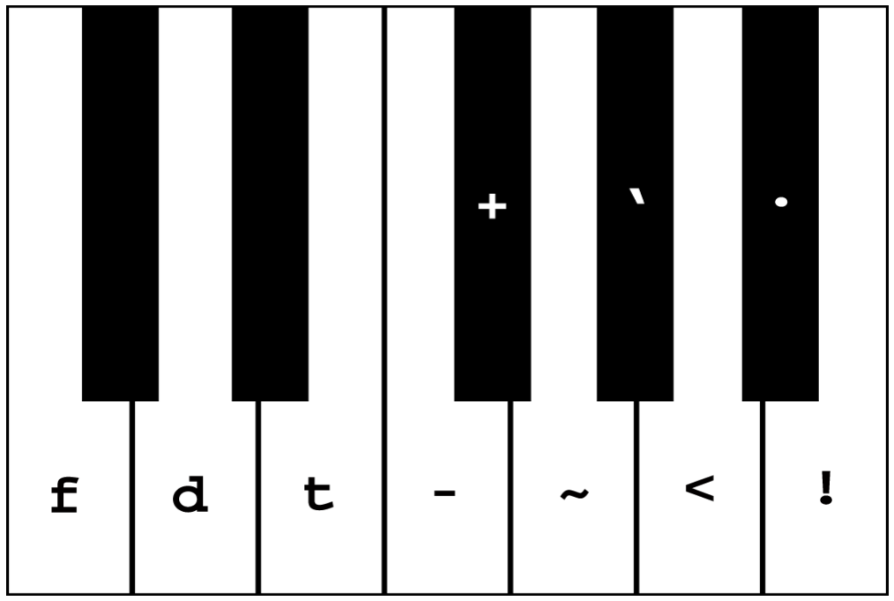
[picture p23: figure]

## effects>

b | select bsf effect
l | select lpf effect
0 thru 8 | select effect by number (0 - bsf; 1 - lpf)
. | mute all effects
< | unmute all effects
! | reset all effects
? | list effects
ESC or ` | exit effects panel
left button | right button
Press | Press
Tap | Tap
Double-Tap exit effects panel | Double-Tap

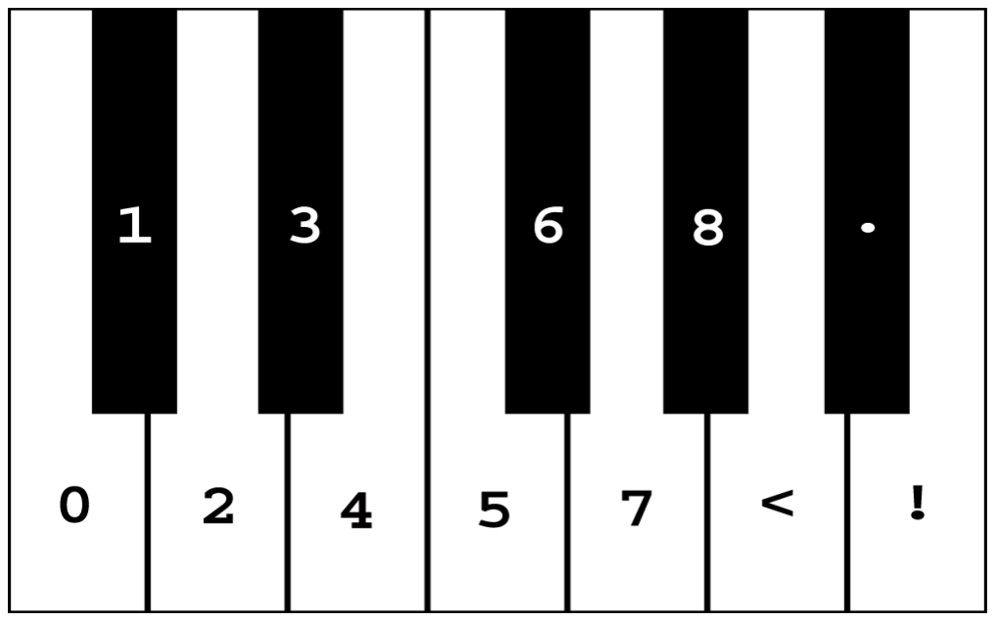
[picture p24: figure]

## bsf> (Binary Shift Filter)

c | set number of bits to clip (0-7)
s | set number of bits to shift (0-7)
+ | normal filter output
- complement filter output
. | mute
< | unmute
! | reset
? | display filter state
ESC or ` | exit filter panel

(continued ...)

## bsf

left button | right button
Press | Press
Tap -1 octave | Tap +1 octave
Double-Tap exit filter panel | Double-Tap run key menu once

## shift clip

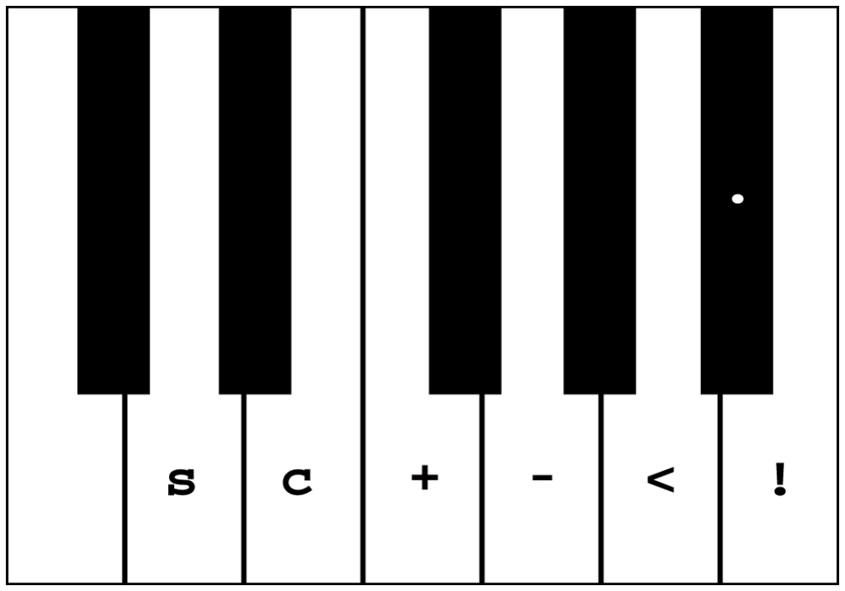
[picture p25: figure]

## lpf> (Low-Pass Filter)

c | set cutoff freq level (parts per 255: 0-255)
. | mute
< | unmute
! | reset
? | display filter state
ESC or ` | exit filter panel

(continued ...)

## lpf

left button | right button
Press | Press
Tap -1 octave | Tap +1 octave
Double-Tap exit filter panel | Double-Tap run key menu once

## cutoff

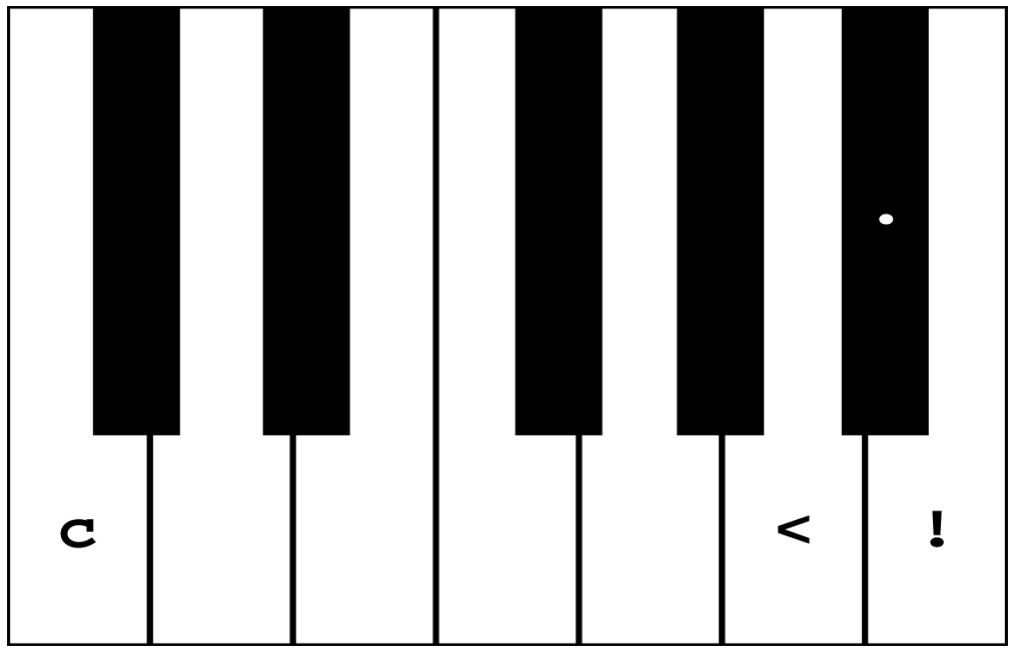
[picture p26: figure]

## preset>

0 thru 9 | select preset by number (0, 1, 2, 3, 4)
? | list presets
ESC or ` | abort preset selection
left button | right button
Press | Press
Tap | Tap
Double-Tap abort preset selection | Double-Tap

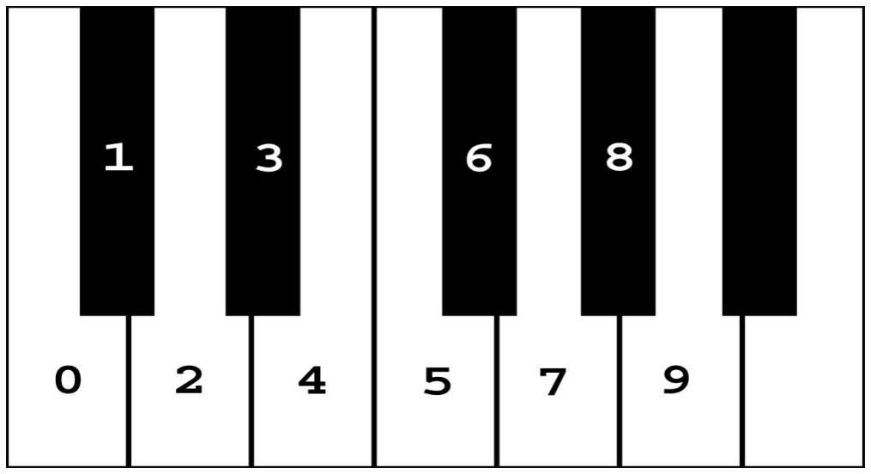
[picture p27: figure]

## waveform>

0 thru 9 | select waveform by number (0, 1, or 2)
? | list waveforms
ESC or ` | abort waveform selection
left button | right button
Press | Press
Tap | Tap
Double-Tap abort waveform selection | Double-Tap

## (numeric input)

### 0 thru 9 decimal digit

- minus sign
. | decimal point
CR or / | commit input
ESC or ` | abort input
left button | right button
Press | Press | commit input
Tap | Tap | commit input
Double-Tap | abort input | Double-Tap

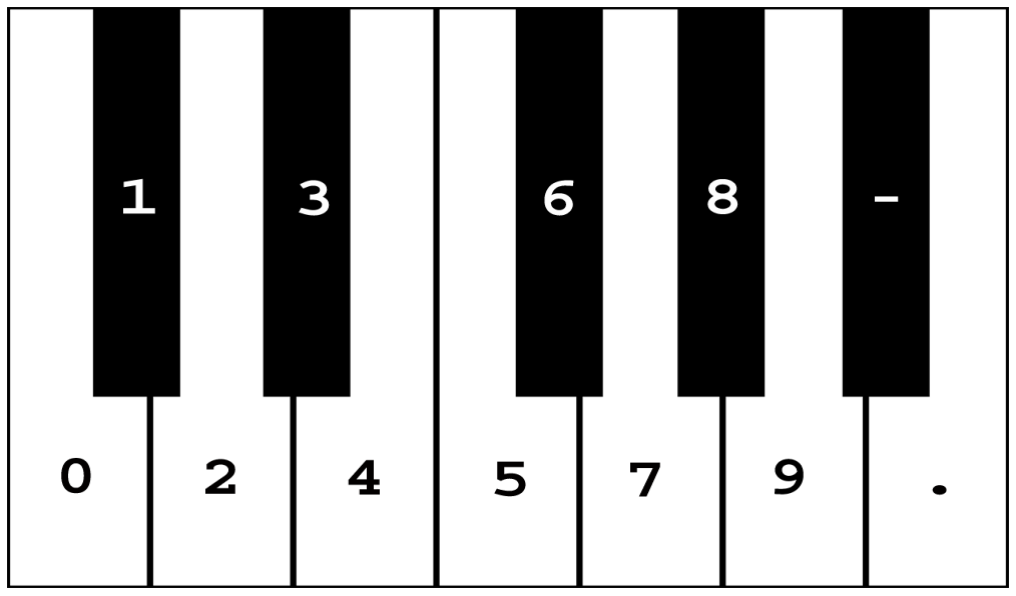
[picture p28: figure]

## keybrd>

z | C
s | C#
x | D
d | D#
c | E
v | F
g | F#
b | G
h | G#
n | A
j | A#
m | B
, | high C
0 thru 8 | select octave 0 thru 8
? | display current octave
ESC or ` | exit virtual keyboard
left button | right button
Press | Press
Tap - 1 octave | Tap + 1 octave
Double-Tap exit virtual keyboard | Double-Tap

Types of button presses:

Tap: | quickly tap a button
Press: | long‐press a button
Double‐Tap: | quickly double‐tap a button
Tap‐Press: | think of this as a Double‐Tap but with the second tap being of a longer
| duration.

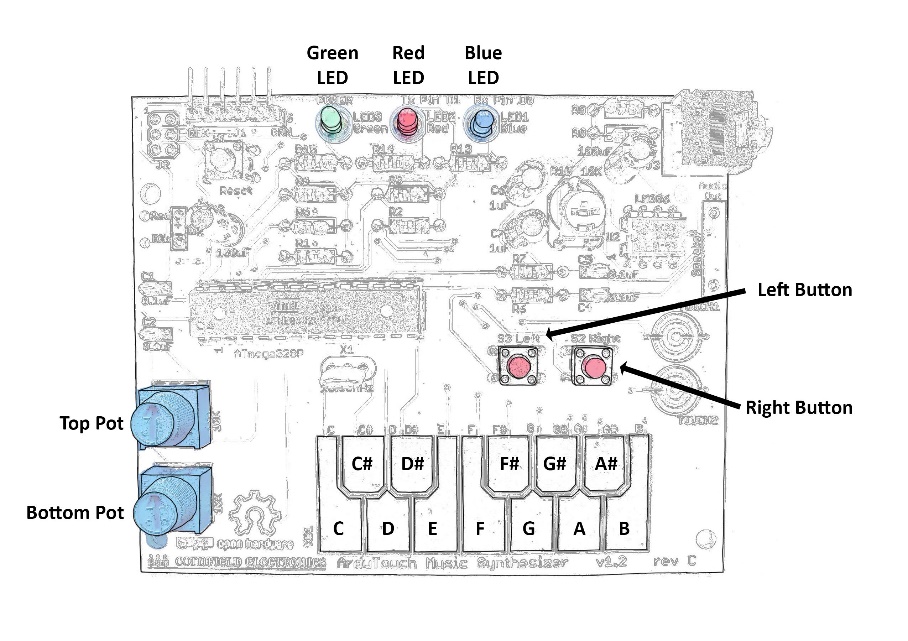
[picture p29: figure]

Copyright (C) 2020, Cornfield Electronics, Inc.

This work is licensed under the Creative Commons Attribution-ShareAlike 4.0
Unported License.

To view a copy of this license, visit http://creativecommons.org/licenses/by-sa/4.0/

Created by Bill Alessi & Mitch Altman.

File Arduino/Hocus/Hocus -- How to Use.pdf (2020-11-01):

## Hocus

A synth organ with 4 transposable tone wheels, 29 built‐in registrations, 2 rotary speaker effects with a simulated Leslie foot‐switch and some crazy multi‐interval vibratos.

How to use:

-------- Presets --------

There are lots of really nice presets!

A list of all Presets can be seen on page 8 of this document.

Load preset sounds by Double-Tapping the right button and then pressing any "white" key.

Note: A list of all types of button presses this synth uses, including “Double-Tapping” can be seen on page 9 of this document.

Play with these presets, and check out the cool Leslie effects as you play notes on the keyboard!

If you want to have more control over lots of cool and warped sounds available with the Hocus synth, the following pages will explain how.

==== Audio Flow Diagram for the Hocus Organ ====

| Tone Wheel 0 | | Tone Wheel 3 | | Tone Wheel 1 | | Tone Wheel 2 |
v | v | v | v
| <--- Rotary 0.3 ---> | | | <--- Rotary 1.2 ---> |
| v | v | v | v
| | L0 | R0 | L1 | R1 | |
| | Mixer | |
| | | L0 + L1 | R0 + R1 | | |
| | Audio out | |
v | v

The audio outputs of tone wheels 0 and 3 are fed into Rotary 0.3 (a rotary speaker effect) which dynamically pans them in stereo and sends the stereo output to the Mixer as inputs L0 and R0.

Likewise, the audio of tone wheels 1 and 2 are fed into Rotary 1.2, which sends its output to the Mixer as inputs L1 and R1.

The Mixer combines inputs L0 and L1, and inputs R0 and R1, to produce a master stereo signal out.

==== The Tone Wheel ====

Each Tone Wheel contains a Registration control, a Transpose control, a Vibrato, a Gain, and a Percussive Decay.

R E G I S T R A T I O N | T R A N S P O S E
================================================= | ============
| | | | | | | | | | | | | ^ | +12 |
| | H a r m o n i c s | | | | . | |
| | | 1 | 2 | 3 | 4 | 5 | 6 | 7 | 8 | 9 | | | | . | |
| | |-------------------------------------| | | | . | +6 |
| | 1 | . | . | | . | | . | | . | | | | | . | |
| | 2 | . | . | | . | | . | | . | | | | | . | . |
| | 3 | . | . | | . | | . | | | | | | | . | |
| | 4 | . | . | | . | | . | | | | | | | . | 0 |
| | 5 | . | . | | . | | | | | | | | | . | |
| | 6 | . | . | | . | | | | | | | | | . | . |
| | 7 | . | . | | | | | | | | | | | . | |
| | 8 | . | . | | | | | | | | | | | . | -6 |
| | 9 | . | | | | | | | | | | | | . | |
| | 10 | . | | | | | | | | | | | | . | . |
| | | | | | | | | | | | | v | -12 |
================================================= | ============
V I B R A T O | G A I N
================================================= | =============
| | FREQ | DEPTH | | | | | Level | |
| | FADE | | | | | |
| | -------------------------- | | | | Overdrive |
| | | | Time | | In or Out | | | | | --------- |
| | -------------------------- | | | | On or Off |
| | SHAPE | RANGE | INTERVAL | | | =============
| | | Triangle | | | Positive | | | 1 . 12 | | | | D E C A Y
| | | Rising | | | | Negative | | ---------- | |
| | | Falling | | | Pos & Neg | | | | =============
| | | Square | | | ------------- | | | | | |
| | ------------ | | | | | Time | |
================================================= | =============

The REGISTRATION control is what produces the basic sound of the tone wheel. It mixes the fundamental frequency for the tone with one or more harmonics, each at its own volume level. This is similar to the drawbars found on some electric organs. Unlike electric organs Hocus does not allow you to inter-actively move individual drawbars. Instead it pre-figures them in a number of set registrations which can be selected via a pot (see below). In the diagram above the selected registration mixes the fundamental at 100% with the 2nd harmonic at 80% with the 4th harmonic at 60% with the 6th harmonic at 40% with the 8th harmonic at 20%.

The TRANSPOSE control shifts the tone wheel's pitch, in semi-tone increments, from the note played. For example, if the transpose for a given tone wheel is set to +7, then a 'C' played on the keyboard will sound as the 'G' above it.

The VIBRATO has the following seven parameters:
1) FREQ | - frequency of vibrato
2) DEPTH | - intensity of vibrato
3) FADE TIME - amount of time over which to fade the vibrato in or out.
| (if this value is 0 then the fade is disabled).
4) FADE DIR - direction of fade: fade in or fade out
5) SHAPE | - the vibrato waveform:
| triangle wave
| rising sawtooth
| falling sawtooth
| square wave
6) RANGE | - the range over which the vibrato fluctuates:
*positive : fluctuate from above the note played to the note played *negative : fluctuate from below the note played to the note played *pos & neg : fluctuate from above the note played
| to below the note played
7) INTERVAL - the maximum number of semitones (1 to 12) over which
| to range (assuming DEPTH is 100%)

Note: a "normal" organ vibrato would have a FREQ of around 3, a DEPTH of 25%, a FADE TIME of 0 (meaning no fade), a SHAPE of Triangle, a RANGE of Pos & Neg, and an INTERVAL of 1.

The GAIN control adds distortion to the tone. When Overdrive is on, the effect becomes nonlinear :)

If the Time parameter for the Percussive DECAY is non-zero then the tone volume will decay to silence over that period of time once played. This mimics the action of percussive stops found on some electric organs.

==== PLAYING THE KEYBOARD ====

Hocus is a mono-touch instrument: you can play one note at a time.

To raise the keyboard by an octave, Tap the right button once. To lower the keyboard by an octave, Tap the left button once.

==== AUTO-SUSTAIN ====

Like a normal organ Hocus will stop sustaining a note once you lift your finger from the key.

Hocus has an auto-SUSTAIN feature which, when enabled, is like having a sustain pedal constantly depressed. Notes will sustain indefinitely.

You can stop a sustaining note by pressing it's key again.

The auto-SUSTAIN feature is enabled and disabled via the Settings Menu (see below).

==== SIMULATED LESLIE FOOT-SWITCH ====

The classic Leslie rotary speaker came equipped with a dual foot-switch for ramping the rotation speed of the speaker. By stepping on the right foot-switch the rotation of the speaker would gradually accelerate to a fast speed. By stepping on the left foot-switch the rotation of the speaker would gradually decelerate to a slow speed.

Hocus simulates this foot-switch via a Tap-Press on the two on-board buttons. (Think of a Tap-Press as a Double-Tap, but with the 2nd tap held for a longer period of time).

To accelerate the speed of the rotary speakers, Tap-Press the right button.

To decelerate the speed of the rotary speakers, Tap-Press the left button.

You can continue playing while the rotary speakers are changing speeds. In fact, it can really liven up the sound if you change the rotation speed back and forth as you play.

Note: Certain presets (see below) internally restrict the rotary position of the speakers. When these presets are being used the simulated Leslie foot-switch will have little audible effect.

==== USING THE POTS TO CONTROL PARAMETERS ====

The pots can be used to control 18 different parameters, a pair at a time.

By Pressing (not Tapping) the left and right buttons you can change which pair of parameters the pots control. Each time a button is Pressed, its associated LED (red LED for left button, blue LED for right button) will change state (from OFF to ON to BLINKING, back to OFF etc.)

Below is a chart showing which pair of parameters the pots control when the LEDs are in a given state.

Note: ' before a parameter name indicates that changes to the parameter are applied to the currently SELECTED tone wheel only. The selected tone wheel can be changed via the Settings Menu (see below).

red LED | blue LED | top POT | bot POT
OFF | OFF | 'REGISTRATION | 'TRANSPOSE
ON | OFF | 'VOLUME | 'DETUNE
BLINK | OFF | 'percussive DECAY | 'vibrato INTERVAL
OFF | ON | 'vibrato FREQ | 'vibrato DEPTH
ON | ON | 'vibrato SHAPE** | 'vibrato RANGE***
BLINK | ON | 'vibrato TIME | 'vibrato FADE****
OFF | BLINK | 'gain LEVEL | 'gain OVERDRIVE*
ON | BLINK | rotary 0.3 FREQ | rotary 0.3 DEPTH
BLINK | BLINK | rotary 1.2 FREQ | rotary 1.2 DEPTH

' changes are applied to the SELECTED tone wheel only

* left-of-middle = overdrive OFF, right-of-middle = overdrive ON

** from left to right, in 45-degree increments:
Triangle / Rising Sawtooth / Falling Sawtooth / Square.

*** from left to right, in 60-degree increments:
positive and negative / positive / negative

**** left-of-middle = FADE In, right-of-middle = FADE Out

==== ENSEMBLE vs ISO OUTPUT ====

Hocus normally outputs audio from all 4 tone wheels in stereo as depicted in the Audio Flow Diagram (see first page).

It is also possible to output the audio of just the SELECTED tone wheel, bypassing the rotary effects and mixer. This is called ISO output.

ISO output is useful when you want to hear exactly how edits to a tone wheel's parameters effect its sound, without being distracted by the output from the other tone wheels.

ENSEMBLE and ISO output are set via the Settings Menu (see below).

ENSEMBLE output is automatically restored when a preset is loaded.

==== USING THE SETTINGS MENU ====

You can change various aspects of Hocus by using the Settings Menu.

To access the Settings Menu Double-Tap the left button. The LEDs will now start blinking on and off in alternation: this tells you that the Settings Menu is active. When the Settings Menu is active the keys will no longer play notes but each key will choose a particular setting as described below.

The Settings Menu is active until you press a key on the keyboard, after which the Settings Menu is automatically exited (restoring the prior user interface state).

You can exit the Settings Menu without choosing a setting by Double-Tapping the left button a second time.

The list below describes what actions are taken when a key on the keyboard is pressed:

Key | Action
C | SELECT tone wheel 0
D | SELECT tone wheel 1
E | SELECT tone wheel 2
F | SELECT tone wheel 3
G | SUSTAIN On
A | SUSTAIN Off
A# | ISO | output
B | ENSEMBLE output

==== Guide to Hocus Presets ====

Load presets by Double-Tapping the right button and then pressing any key on the keyboard.

The presets are as follows:

Key | Name | Description
C | Stock | stock "simple" organ sound
C# | Rocker* | distortion on lower 2 tone wheels
D | Perc | percussive decay on tone wheels 2 & 3
D# | Friction* | overdriven gain and octave-widening vibrato on
| | tone wheels 0 & 3
E | Pipe | multiple registrations
F | Punchy | gain on tone wheel 2; 7 Hz vibrato on tone wheel 3
F# | Pipe2 | multiple registrations
G | Murk | dark intervals; slow rising-sawtooth vibrato fading
| | out on tone wheel 2
G# | Farfisa* | cheezy vibrato; registrations use a mix of odd and
| | even harmonics
A | Perc2 | percussive decay on tone wheels 2 & 3
A# | GiddyUp | fun with square-wave vibratos
B | area51 | detuned tones and opposing saw-tooth vibratos with
| | minor-3rd ranges

* restricted rotary positions: Leslie foot-switch has little effect

Types of button presses:

Tap: | quickly tap a button
Press: | long‐press a button
Double‐Tap: | quickly double‐tap a button
Tap‐Press: | think of this as a Double‐Tap but with the second tap being of a longer
| duration.


Copyright (C) 2020, Cornfield Electronics, Inc.

This work is licensed under the Creative Commons Attribution-ShareAlike 4.0
Unported License.

To view a copy of this license, visit http://creativecommons.org/licenses/by-sa/4.0/

Created by Bill Alessi & Mitch Altman.

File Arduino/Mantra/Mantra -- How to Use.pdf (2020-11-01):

1

## Mantra

A play‐along synth in an Indian‐like exotic scale. You can’t play a wrong note.

How to use:

There are two drone sequences which you can play along to. We call these: Drone A and Drone B.
Each drone consists of:
percussion, bass, and a melodic obligato part

Drone A is pre-loaded and ready to play when Mantra is turned on.

To start the drone: Press the left button. The red LED will begin blinking, and the drone will begin playing. Now you can play a "lead" over it.

To stop the drone: Press the left button again. The red LED will stop blinking.

To choose drone B: Double-Tap the right button and press D on the keyboard.
To choose drone A: Double-Tap the right button and press C on the keyboard.

The keyboard is tuned to an exotic scale.

The "white" keys are the scale itself (so you can't go wrong if you just stay on the white keys :)

The "black" keys repeat the note of a neighboring white key with an added "bend" to the note.

The top pot controls the portamento speed of the lead voice. Turning it all the way to the right turns portamento off.

The bottom pot controls the speed and intensity of an autowah effect on the lead voice. Turning it all the way to the left turns the autowah off.

To raise the lead voice by an octave, Tap the right button once. To lower the lead voice by an octave, Tap the left button once.


2

Types of button presses:

Tap: | quickly tap a button
Press: | long‐press a button
Double‐Tap: quickly double‐tap a button

Copyright (C) 2020, Cornfield Electronics, Inc.

This work is licensed under the Creative Commons Attribution-ShareAlike 4.0
Unported License.

To view a copy of this license, visit http://creativecommons.org/licenses/by-sa/4.0/

Created by Bill Alessi & Mitch Altman.

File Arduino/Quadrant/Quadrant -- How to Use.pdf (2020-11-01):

## Quadrant

A partly echoing, partly arpeggiating, possibly warped synth for the ArduTouch.

How to use:

-------- Presets --------

There are lots of way cool presets!

A list of all Presets can be seen on page 8 of this document.

Load preset sounds by Double-Tapping the right button and then pressing any "white" key.

Note: A list of all types of button presses this synth uses, including “Double-Tapping” can be seen on page 8 of this document.

Once you choose a preset, play notes on the keyboard and twiddle the knobs while playing and see what beautiful and also warped sounds and music you can create!

If you want to have more control over lots of cool and warped sounds available with the Quadrant synth, the following pages will explain how.

==== Audio/Control Flow Diagram for the Quadrant Synth ====

| Tropes | --------.
v
.-----------> | | Echotron | |
| | v | v | v
| Lead 0 | ---> | | Mixer | | <--- | Lead 1 |
| v | v

[ Audio out ]

Lead 0 is duplicated in the opposite audio channel by Lead 1 (which may be transposed and/or detuned from Lead 0). The note information for Lead 0 is also fed into the Echotron. At the same time, a "trope" (an arpeggiation pattern) can be applied to the echoed note. The output from the Echotron is internally panned in stereo and then fed into a mixer along with the audio output from Lead 0 and Lead 1.

==== The Echotron Unit ====

The Echotron is a stereo synthesizer in its own right.

At the heart of the Echotron is a carousel of "slots", each of which holds an instance of an echoing note:

| | | | <--- WARP FACTOR
| | Note Carousel | |
| | | | <--- DELAY TIME
| Slot 0 < Slot 1 < Slot 2 < Slot 3 |
| | | | <--- FEEDBACK
v
note out

The carousel is constantly "revolving", outputting the note held in the current slot (the left-most slot in the above diagram), then shifting the slots.

The speed at which the carousel revolves is controlled by the DELAY TIME.

Each time a note echoes its volume will decrease by an amount controlled by the FEEDBACK setting. If FEEDBACK is set to its highest value (255) then the note will echo forever, or until all the slots in the carousel have been used up, and a new incoming note "overwrites" it.

Each time a note echoes its pitch can be raised or lowered by the current WARP FACTOR.

The number of slots in the carousel is configurable and can be set interactively via the Parameter Menu (see below) to between 1 and 4.

----- Tropes ------

The above description of the note carousel is a simplification. In fact, each slot can contain not just a note, but also a pointer to a "trope" (an arpeggiation pattern) in ROM. Each time the carousel revolves it will play the next note in the arpeggiation pattern for that slot.

----- Note HOLD ------

You can instruct the Echotron to HOLD the next note played (see the Parameter Menu below). When a note is on HOLD it will not decrease in volume as it echoes, and it will not be overwritten by incoming notes when the carousel is full. This is a very useful feature for setting up a constant bass pulse and jamming over it. Better yet, if a trope is active when you hold the note, then you can set up a whole bass line or texture to be played over. And you can hold more than one note :)

----- SAMPLE & HOLD ------

You can globally freeze whatever sound loop the Echotron is producing by enabling SAMPLE & HOLD (toggled via the Parameter Menu, see below). Then you can jam over it freely.

----- ISO-TEMPO -------

This feature allows the Echotron to maintain a constant tempo, regardless of the number of notes in the carousel. So if there are 4 notes currently echoing in the carousel and ISO-TEMPO is on, then the delay time will be 1/4 of what it would be if there were only 1 note in the carousel. The "Telepromt" and "Frara Jaqua" presets use ISO-TEMPO. You can toggle ISO_TEMPO via the Parameter Menu (see below).

----- ENVELOPE ------

A master envelope dynamically controls the amplitude of the notes produced by the Echotron. This envelope is a traditional ADSR (Attack/Decay/Sustain/Release) but with a twist: a Sustain Time parameter is added. When the envelope for an echoing note reaches the sustain stage it will automatically release after the
amount of time specified by the sustain time parameter. The various stages of the master envelope can be controlled via the pots (see below).

----- PULSE WIDTH ------

The notes produced by the Echotron use square wave oscillators. The PULSE WIDTH of these oscillators can be modified via a pot (see below). The pulse width controls the ratio between the positive and negative edges of the square wave and can radically alter the timbre of the tones.

----- AUTO-WAH ------

The Echotron has a pair of internal autowahs (oscillating low-pass filters) which are applied to the note output before it is panned. Three parameters control the autowah behaviour: CUTOFF frequency, oscillation FREQ, and oscillation DEPTH. All of these can be modified via the pots (see below).

----- PAN CONTROL ------

A PAN control dynamically rotates the note output in the stereo field. The DEPTH and FREQ of the panning can be controlled via the pots (see below).

==== Overview Diagram of the Echotron ====

Now that we have covered each component, here is an overall view:

[HOLD] | notes | in | [SAMPLE & HOLD]
\ | |
\ | v
----------------- | < WARP >
Trope in ---> | | Note Carousel | | < DELAY > | [ISO-TEMPO]
----------------- | < FEEDBACK >
------------- | | | < # SLOTS >
| ENVELOPE | | notes | out
| <Attack> | | |
| <Decay> | | | v
| <Sustain> | | -----------------------------
| <SusTime> | | | | AutoWahs | |
| <Release> | | | <CUTOFF> <FREQ> <DEPTH> |
v | v
-----------------------------| <---- Pan Control ----> |
| | <FREQ> <DEPTH> | |
| | audio out | |
v | v

==== PLAYING THE KEYBOARD ====

The Quadrant keyboard is a mono-touch instrument: you can play one note at a time.

To raise the keyboard by an octave, Tap the right button once. To lower the keyboard by an octave, Tap the left button once.

==== USING THE POTS TO CONTROL PARAMETERS ====

The pots can be used to control 18 different parameters, a pair at a time.

By Pressing (not Tapping) the left and right buttons you can change which pair of parameters the pots control. Each time a button is Pressed, its associated LED (red LED for left button, blue LED for right button) will change state (from OFF to ON to BLINKING, back to OFF etc.)

Below is a chart showing which pair of parameters the pots control when the LEDs are in a given state:

red LED | blue LED | top POT | bottom POT
OFF | OFF | echo WARP | echo DELAY time
ON | OFF | echo FEEDBACK | lead/echo BALANCE
BLINK | OFF | panning FREQ | panning DEPTH
OFF | ON | autowah FREQ | autowah DEPTH
ON | ON | autowah CUTOFF | echo PULSE WIDTH
BLINK | ON | lead 1 DETUNE** | lead 1 TRANSPOSE***
OFF | BLINK | envelope ATTACK* | envelope DECAY*
ON | BLINK | envelope SUSTAIN* | envelope RELEASE*
BLINK | BLINK | echo SUSTIME | lead PORTAMENTO

* these pots can be configured via the Parameter Menu (see next section) to control:
1) only the LEAD voices
2) only the ECHO voices
3) both the LEAD and ECHO voices

** detunes lead1 from lead 0

*** transposes lead1 from lead0 (range is from -2 to +2 octaves)

==== USING THE PARAMETER MENU ====

You can control additional parameters by using the Parameter Menu.

To access the Parameter Menu Double-Tap the left button. The LEDs will now start blinking on and off in alternation: this tells you that the Parameter Menu is active. When the Parammeter Menu is active the keys will no longer play notes but each key will select and modify a particular parameter as described below. Depending on the parameter, the pot positions may also be relevant, as described below. The Parameter Menu is active until you press a key on the keyboard: then the parameter associated with that key is modified, and the Parameter Menu is automatically exited (restoring the prior user interface state).

You can exit the Parameter Menu without modifying any parameters by Double-Tapping the left button a second time.

The list below describes what actions are taken when a key is pressed:

Key | Action
C | toggle Sample-and-Hold on/off
C# | turn Sample-and-Hold off, and unhold all held notes
D | hold next note played
D# | [ reserved ]
E | toggle lead voices on/off
F | set # of slots in carousel based on pot 0 position *
F# | toggle isoTempo or/off
G | select trope based on pot 1 position **
G# | [ reserved ]
A | ADSR pots control envelopes of both lead and echo voices
A# | ADSR pots control envelopes of lead voices only
B | ADSR pots control envelopes of echo voices only

* turn pot 0 to desired position (all the way left = 1, all the way right = 4) then press F

** turn pot 1 to desired position (all the way left = "no trope" ) then press G

==== GUIDE TO QUADRANT’S PRESETS ====

Load presets by Double-Tapping the right button and then pressing any "white" key.

The presets are as follows:

Key Name | Performance Notes
C | Scaffold | lead voices off (and should stay off)
D | Farsy
E | Teleprompt lead voices off (turn them on once 2 slots are playing)
F | Glacial | play very slowly
G | Blur
A | ToneJack
B | FraraJaqua lead voices off (turn them on once 4 slots are playing)

Types of button presses:

Tap: | quickly tap a button
Press: | long‐press a button
Double‐Tap: quickly double‐tap a button


----------------------------------------------------------------------About Quadrant's Tuning

When you start playing notes on the keyboard you will probably notice that the 'C' key plays an 'F'. And if you have a really good ear you may also notice that the interval between C# and G# is not exactly a 5th.

Why is this?

To explain the 2nd observation first, Quadrant uses Harmonic Tuning (also known as Just Temperament or "Helmholtz's scale") instead of the usual Equal Temperament (which is the system default).

Harmonic Tuning is actually more "natural" than Equal Temperament (which was created as a compromise so that keyboard instruments could play in all keys). In Harmonic Tuning the relative frequencies of all notes compared to the tonic ('C' in our case) are rational numbers:

Unison | 1/1
Minor Second 25/24
Major Second | 9/8
Minor Third | 6/5
Major Third | 5/4
Fourth | 4/3
Diminish 5th 45/32
Fifth | 3/2
Minor Sixth | 8/5
Major Sixth | 5/3
Minor Seventh 9/5
Major Seventh 15/8
Octave | 2/1

The Echotron uses quantum square wave oscillators which can only be set to frequencies which have integral wavelengths. The frequencies produced by these oscillators conform more closely to a scale in Harmonic Tuning than one in Equal Temperament.

But why does the 'C' key play an 'F'?

The short answer is that on the ArduTouch, whose audio rate is ~15.6 kHz, 'F' (in octave 1) has a period of 360 samples. 360 is a number favored by the ancients because it is divisible by a large number of integers: 1, 2, 3, 4, 5, 6, 8, 9, 10, 12, 15, 18, 20, 24, etc. It so happens that by using a tonic frequency whose period is 360, we are able to use quantum oscillators to closely approximate the Harmonic Tuning scale over several octaves. Low 'F', so to speak, is the natural tonic frequency of the ArduTouch.*

Since Quadrant's tuning is only an approximation to an 'F' Harmonic tuning, certain musical scales (such as E Major, F# Major on the ArduTouch keyboard) will sound a bit sour. C Major / D Minor work best.

* Actually, on the ArduTouch a waveform with a period of 360 samples generates a tone with a frequency of 43.578 Hz. In the equal temperament scale, 'F' in octave 1 has a frequency of 43.654 Hz.

Copyright (C) 2020, Cornfield Electronics, Inc.

This work is licensed under the Creative Commons Attribution-ShareAlike 4.0
Unported License.

To view a copy of this license, visit http://creativecommons.org/licenses/by-sa/4.0/

Created by Bill Alessi & Mitch Altman.

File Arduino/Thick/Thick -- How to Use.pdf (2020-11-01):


1

## Thick

A 4‐voice unison synth employing pre‐figured saw‐tooth oscillators.

How to use:

1) Press the keys on the keyboard to play notes
2) Tap left button to lower keyboard by 1 octave
3) Tap right button to raise keyboard by 1 octave
4) Press the left button to use a unison tuning
5) Press the right button to use a spread tuning with 5ths and octaves.
6) Bottom pot controls portamento speed (clockwise for lower speed, all the way counter-clockwise is portamento off)
7) Top pot graduates the portamento speed of each voice so that they run at different rates (clockwise for greater divergence, all the way counter-clockwise for no difference in speeds)

Types of button presses:

Tap: | quickly tap a button
Press: | long‐press a button

2

Copyright (C) 2020, Cornfield Electronics, Inc.

This work is licensed under the Creative Commons Attribution-ShareAlike 4.0
Unported License.

To view a copy of this license, visit http://creativecommons.org/licenses/by-sa/4.0/

Created by Bill Alessi & Mitch Altman.

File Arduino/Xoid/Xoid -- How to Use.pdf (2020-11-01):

## Xoid

An XORing synth to make great digital sounds and noise!

How to use:

==== Presets ====

There are lots of way cool presets! Some are even noisier than the rest.

Try them out! Load preset sounds by Double-Tapping the right button and then pressing any "white" key.

Play with these presets, and you can make lots of crazy digital sound and noise!

Please see page 3 of this document for a list of all types of button presses (including “Double-Tapping”) you can use on this synth.

==== Diagram of the Xoid Voice ====

| Oscillator Section | --> envelope --> Gain --> AutoWah --> [output]
^
Vibrato

==== Diagram of the Oscillator Section ====

pair0
Osc 1 ----> | | | | -------
| XOR | | ----> | | | |
Osc 2 ----> | | | | | | |
| XOR | ---> [output]
Osc 3 ----> | | | | | | |
| XOR | | ----> | | | |
Osc 4 ----> | | | | -------
------- | combo
pair1

==== After loading a preset, you can mess with the sound! ====

Try Pressing and Tap-Pressing the buttons and twiddling the pots, and see what kind of crazy sounds and noise you can get!

If you want to get really good at Xoid, it takes practice.

Xoid has a lot of combinations. What follows is an explanation:

Each LED can be in one of 3 states : OFF - ON - BLINKING

The LEDs indicate what parameters the pots control:

Red LED | Blue LED | top POT | bot POT
OFF | OFF | combo XOR mix | combo freq ratio
ON | OFF | pair0 XOR mix | pair0 freq ratio
BLINK | OFF | pair1 XOR mix | pair1 freq ratio
OFF | ON | env ATTACK | env DECAY
ON | ON | env SUSTAIN | env RELEASE
BLINK | ON | vibrato FREQ | vibrato DEPTH
OFF | BLINK | autowah FREQ | autowah DEPTH
ON | BLINK | autowah ON/OFF | autowah CUTOFF
BLINK | BLINK | gain | portamento

To bump the Red LED state: Press left button
To bump the Blue LED state: Press right button

When the Blue LED is off the Red LED also indicates what happens when you Tap-Press a button (a "Tap-Press" is a double tap with the 2nd tap being of longer duration):

| Tap-Press: |
Red LED | Blue LED | left BUTTON | right BUTTON
OFF | OFF | combo XOR on/off | bump combo freq spectrum
ON | OFF | pair0 XOR on/off | bump pair0 freq spectrum
BLINK | OFF | pair1 XOR on/off | bump pair1 freq spectrum

Note 1: Toggling an XOR function on and off dramatically effects the sound.
Note 2: Bumping the freq spectrum changes the frequency sweep for bottom pot.

For more info on XOR objects and their User Interface (U/I) see example sketches numbered in the 40s.

To raise keyboard by an octave, Tap right button once.
To lower keyboard by an octave, Tap left button once.

Types of button presses:

Tap: | quickly tap a button
Press: | long‐press a button
Double‐Tap: | quickly double‐tap a button
Tap‐Press: | think of this as a Double‐Tap but with the second tap being of a longer
| duration.


Copyright (C) 2020, Cornfield Electronics, Inc.

This work is licensed under the Creative Commons Attribution-ShareAlike 4.0
Unported License.

To view a copy of this license, visit http://creativecommons.org/licenses/by-sa/4.0/

Created by Bill Alessi & Mitch Altman.

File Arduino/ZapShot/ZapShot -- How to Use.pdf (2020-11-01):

## ZapShot

A stereo synth using 2 sweeping quantized square wave oscillators.

How to use:

Start playing the keyboard, you will hear a sound somewhat like the video game "Pong". Press the right button and the Blue LED will start flashing. Now ZapShot is in "auto-trigger" mode, and the sound will automatically keep playing until the right button is Pressed again. This frees up your hands to twist the pots. :)

==== Presets ====

There are six presets. To select a preset Double-Tap the right button and then press a "white" key.

The following presets are available:

Key C - "Pong"
Key D - "Bong"
Key E - "AirRaid"
Key F - "Stuka"
Key G - "Alarms"
Key A - "Quizzle"

Types of button presses:

Tap: | quickly tap a button
Press: | long‐press a button
Double‐Tap: | quickly double‐tap a button

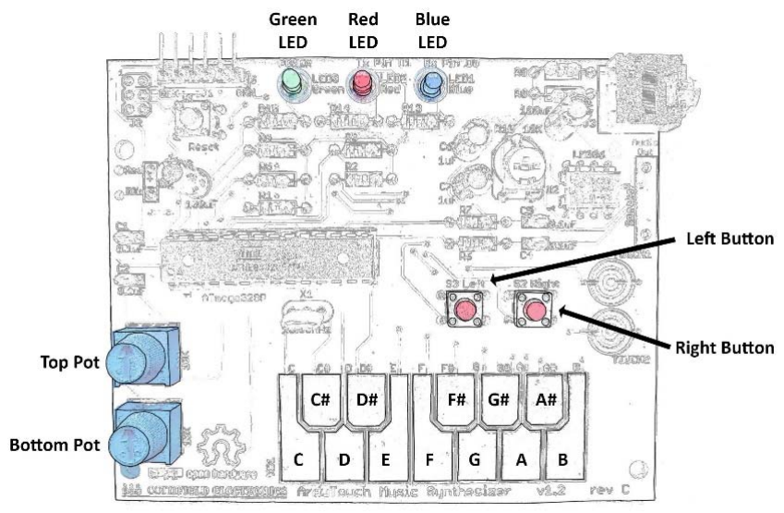
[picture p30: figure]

2

Copyright (C) 2020, Cornfield Electronics, Inc.

This work is licensed under the Creative Commons Attribution-ShareAlike 4.0
Unported License.

To view a copy of this license, visit http://creativecommons.org/licenses/by-sa/4.0/

Created by Bill Alessi & Mitch Altman.

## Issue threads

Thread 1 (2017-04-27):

Include sch/brd source files in repository?

lukeweston, 2017-04-27:
It seems like everything else is nicely presented and included except the actual schematic and board file. :)

maltman23, 2017-04-27:
They are both already in the repository.  The schematic is in the "Schematic" folder, and the Eagle board file (and schematic file) is in the "Eagle" folder.

Closed 2017-12-04.

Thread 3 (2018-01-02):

Beatitude too big?

hpfmn, 2018-01-02:
It seems using a recent Arduino (1.8.5) and avr base library (1.6.20) it is not possible to compile and use the Beatitude example.

Arduino complains that it is too big:

```
Sketch uses 33780 bytes (104%) of program storage space. Maximum is 32256 bytes.
Global variables use 735 bytes (35%) of dynamic memory, leaving 1313 bytes for local variables. Maximum is 2048 bytes.
Sketch too big; see http://www.arduino.cc/en/Guide/Troubleshooting#size for tips on reducing it.
Error compiling for board Arduino/Genuino Uno.
```

Or is there anything else I'm missing?

maltman23, 2018-03-28:
Sorry for the long delay in answering this!
This issue is now addressed in the latest release (28-March-2018).

Beatitude was developed using Arduino software V1.6.6, but when compiled with the latest version of the Arduino software (V1.8.5), the resulting code is too big.  We fixed it by making the drums a little bit lower resolution.  They sound fine!  :)

But, to get full resolution sound of the drums, you can use V1.6.6 of the Arduino software (instead of the latest version), and uncomment the BUILD_166 define statement in "model.h" in the ArduTouch Arduino library.

Closed 2018-03-28.

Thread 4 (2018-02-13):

Call setAttack() on OneVoxSynth setup()

michcan, 2018-02-13:
Hello Mitch and thank you for this nice librairie !
I try to create my own synth sketch. I use the OneSynthVox class. I want to set attack on the creation of the objet. So i called the setAttack() method inside the setup() method, it doesn't work. But it work's inside evHandler() method. What is the best way to get it work ?

#include "ArduTouch.h"               

set_baud_rate( 115200 )

class mysynth : public OneVoxSynth
{
   public:
   void setup()
   {
      OneVoxSynth::setup();
      setAttack(100); // it doesn't work
   }

   boolean evHandler( obEvent e )            // event handler
   {
      switch ( e.type() )
      {
         case KEY_DOWN:                      // a key has been pressed
         {
            setAttack(100); // it work
            return true;                     // KEY_DOWN event was handled
         }
         default:
            return false;                    // ignore all other events
      }
} synth ;

void setup()
{
   ardutouch_setup( &synth );           
}

void loop()
{
   ardutouch_loop();                    
}

maltman23, 2018-03-28:
Sorry for taking so long to answer your question!

Its a good question.  The answer is to be found in the example sketch  _22_Amp_Modifiers.ino, but it should probably be made more explicit:

The reason setAttack() -- or any other setting of control parameters -- will not work when put in the setup() method of the synth is because they will all be wiped out any time the synth is reset. An implicit reset of the synth is conducted by the library at the end of the startup sequence, after setup() has been called -- hence those settings will be lost.

The proper place to put this kind of code is in the "reset handler" of the synth -- the logic which handles '!'  in the charEv(char code) method of the synth.

One way to explain the difference between the code in the 'reset' portion of the synth's charEv() method, and the code in the setup() method is that the former is what gets executed in a soft reset (resetting after the power is already on), and the latter in a hard reset (when you first apply power).

The relevant lines from _22_Amp_Modifiers.ino start at line 238, and are reproduced here:

-------------------  from _22_Amp_Modifiers.ino   (line 238) --------------------

   // We initialize our controls in the reset handler for our synth.
   //
   // The reset handler is the code which is executed when our synth receives
   // a '!' character event.
   //
   // Note: ardutouch_setup() resets the synth before returning.

   boolean charEv( char code )
   {
      switch ( code )
      {
         case '!':                     // reset
         {
            // perform generic reset of the superclass
    
            super::charEv('!');

            //       the following macro will (line-by-line):

            // start keyboard in octave 5,
            // push voice 0
            // set envelope (decay=68, sustain=64, release=100)
            // push amdMods
            // initialize tremolo control (freq=2.5hz, depth=1.0, unmute)
            // pop ampMods and pop voice 0

            console.exe( PSTR( "k5\\`"
                               "0"
                               "ed68\\s64\\r100\\`"
                               "A"
                               "tf2.5\\d1\\<`"
                               "``" ) );

            break;
         }
         default:
            return super::charEv( code );
      }
      return true;
   }

Closed 2018-03-28.

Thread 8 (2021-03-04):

Can't upload sketches in Arduino IDE 1.8.13

clintonthegeek, 2021-03-04:
Hello!

My friend and I each have seperate ArdoTouchs, our own USB serial adaptors from Cornfield (for the U.Do.IT.Duino), and our own computers. He just tried to flash a new .ino file onto his ArduTouch following the instructions from both his Mac and his Windows computer, and told me it wasn't working. So on my own, I set everything up on my Linux box and encountered exactly the same error when uploading:

` Sketch uses 25210 bytes (78%) of program storage space. Maximum is 32256 bytes.
Global variables use 799 bytes (39%) of dynamic memory, leaving 1249 bytes for local variables. Maximum is 2048 bytes.
avrdude: stk500_recv(): programmer is not responding
avrdude: stk500_getsync() attempt 1 of 10: not in sync: resp=0x00
avrdude: stk500_recv(): programmer is not responding
avrdude: stk500_getsync() attempt 2 of 10: not in sync: resp=0x00
avrdude: stk500_recv(): programmer is not responding`

Of course it times out after 10 tries. Since the same problem occurs with multiple versions of the same hardware, on different computers and in every OS, I assume there is something wrong with how the latest Arduino IDE is set up? Or is there some step or troubleshooting step that might be added to the .pdf?

maltman23, 2021-03-10:
Hi Clinton,

If you are getting that error, it means that the Arduino software isn't communicating through the USB-Serial Cable with the ArduTouch board.

I can program my ArduTouch with the latest Arduino IDE v1.8.13, so it isn't a problem with the latest Arduino software.

To debug, can you please answer these questions?
* Are you sure you have chosen the correct Port for your USB-Serial Cable (from:  Tools --> Port)?
* Have you chosen the Arduini Uno board (from:  Tools --> Board)?
* You mention having a U-Do-It-Duino board.  Have you ever successfully programmed in a sketch into it using your USB-Serial Cable and any version of the Arduino software?
* Have you ever successfully programmed a new sketch into your ArduTouch board using your USB-Serial Cable and any version of the Arduino software?
* Do you remember when you and your friend bought your ArduTouch kits?  From where did you get them?

It might be easier if we communicate via email.  My email:  mitch AT CornfieldElectronics DOT com

Best,
Mitch

michaelshmitty, 2023-03-06:
@clintonthegeek I had to make sure CTS (Clear to Send) on the FTDI side is connected to RTS (Request to Send) on the ArduTouch board ([RS-232 RTS, CTS, and RTR](https://en.wikipedia.org/wiki/RS-232#RTS,_CTS,_and_RTR)). Then I have to hit the Reset button on the ArduTouch around the time the Arduino IDE starts uploading the sketch. It may take a few tries. The blue LED on the ArduTouch flashes during the upload.

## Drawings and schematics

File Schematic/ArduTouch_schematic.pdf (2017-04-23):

A

A

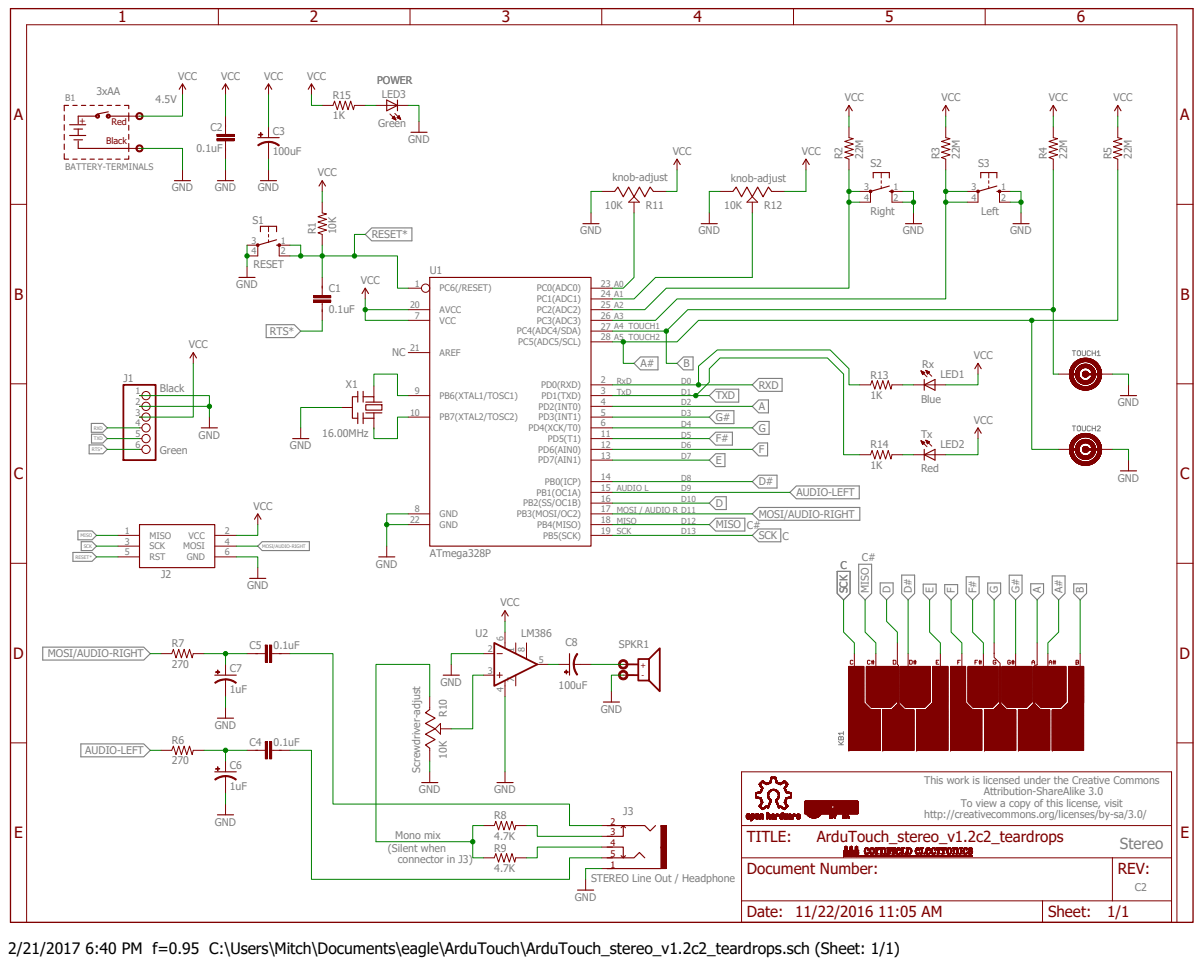
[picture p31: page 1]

This work is licensed under the Creative Commons
To view a copy of this license, visit
http://creativecommons.org/licenses/by-sa/3.0/

2/21/2017 6:40 PM f=0.95 C:\Users\Mitch\Documents\eagle\ArduTouch\ArduTouch_stereo_v1.2c2_teardrops.sch (Sheet: 1/1)

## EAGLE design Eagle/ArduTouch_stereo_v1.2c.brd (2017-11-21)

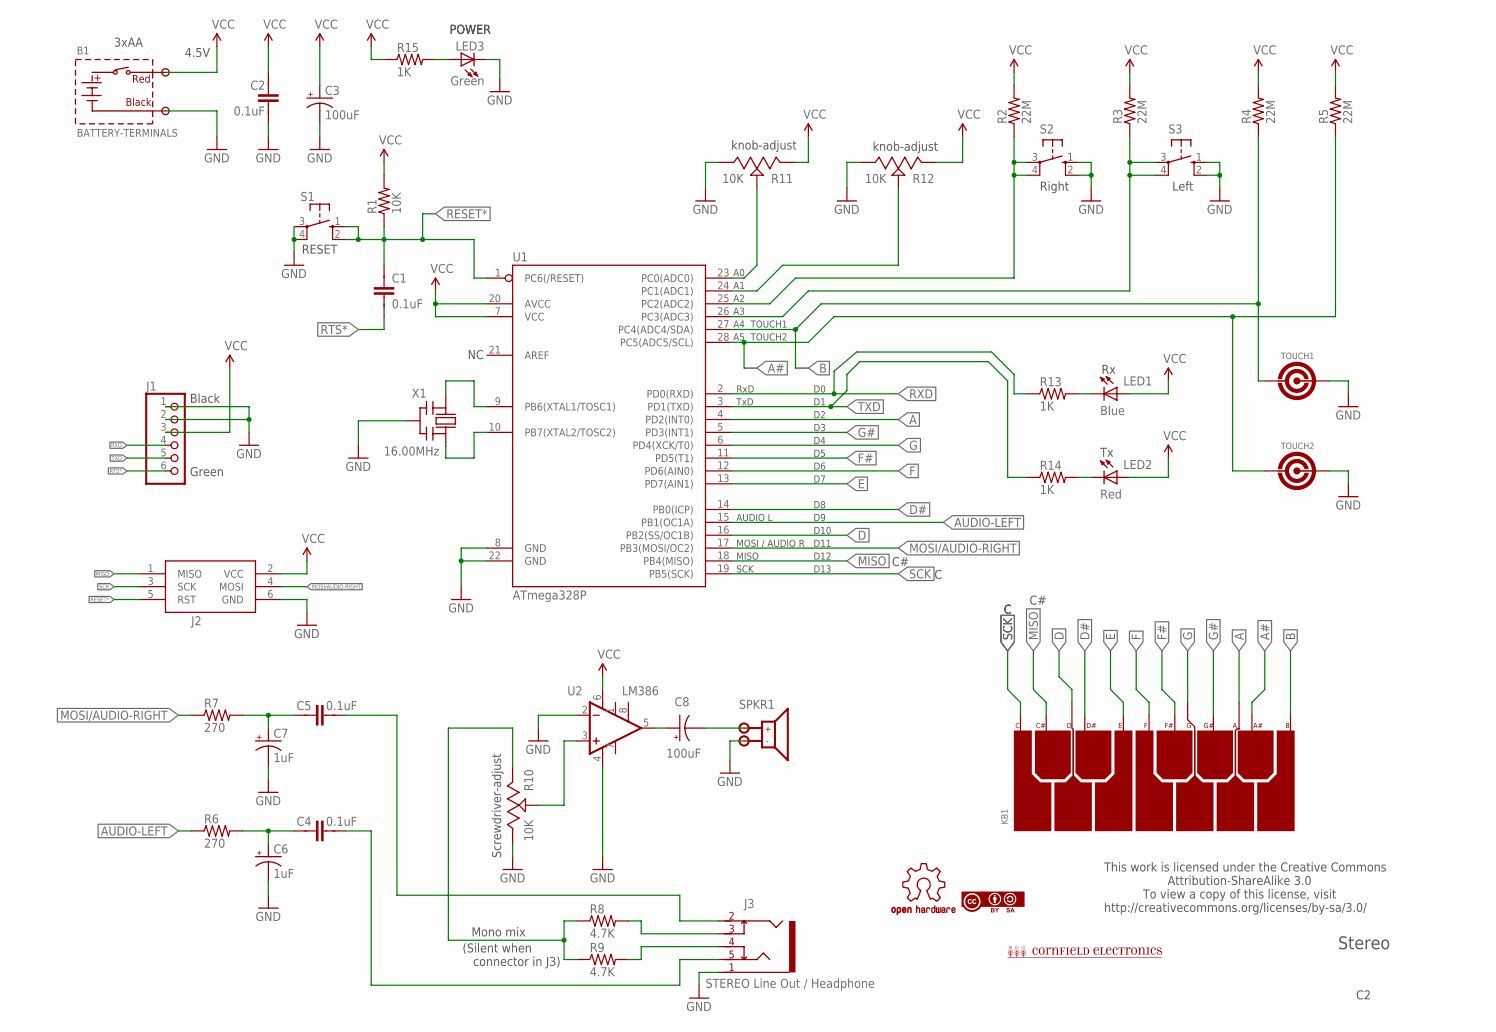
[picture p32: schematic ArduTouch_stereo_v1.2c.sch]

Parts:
B1: BATTERY-TERMINALS
C1, C2, C4, C5: 0.1uF; CAP-PTH-SMALL
C3, C8: 100uF; CPOL-RADIAL-10UF-25V
C6, C7: 1uF; CPOL-RADIAL-10UF-25V
J1: PINHD-1X6LOCK; 1X06-BIGLOCK
J2: ISP; AVRISP
J3: STEREO-AUDIO-3.5MM-SWITCHED
KB1: PCB-KEYBOARD4
LED1: Blue; LED5MM
LED2: Red; LED5MM
LED3: Green; LED5MM
R1: 10K; AXIAL-0.4
R2, R3, R4, R5: 22M; AXIAL-0.4
R6, R7: 270; AXIAL-0.4
R8, R9: 4.7K; AXIAL-0.4
R10: 10K; TRIMPOT-3319P-1
R11, R12: 10K; TRIMPOT-72PTR
R13, R14, R15: 1K; AXIAL-0.4
S1, S2, S3: TACTILE_SWITCH_6.3MM
SPKR1: SPEAKER-TERMINALS
TOUCH1, TOUCH2: PCB-TOUCHPAD2
U1: ATmega328P; DIL28-3
U2: LM386; DIP08
U$1: OSH-LOGO
U$2: CC-BY-SA-LOGO2
U$3: CORNFIELD-LOGO
X1: 16.00MHz; CERM_OSC

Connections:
A: KB1.A, U1.4 (PD2(INT0))
A0: R11.2 (S), U1.23 (PC0(ADC0))
A1: R12.2 (S), U1.24 (PC1(ADC1))
A2: R2.P$1 (1), S2.3, S2.4, U1.25 (PC2(ADC2))
A#: KB1.A#, R5.P$1 (1), TOUCH2.1, U1.28 (PC5(ADC5/SCL))
AUDIO-LEFT: R6.P$1 (1), U1.15 (PB1(OC1A))
B: KB1.B, R4.P$1 (1), TOUCH1.1, U1.27 (PC4(ADC4/SDA))
C+: R3.P$1 (1), S3.3, S3.4, U1.26 (PC3(ADC3))
D: KB1.D, U1.16 (PB2(SS/OC1B))
D#: KB1.D#, U1.14 (PB0(ICP))
E: KB1.E, U1.13 (PD7(AIN1))
F: KB1.F, U1.12 (PD6(AIN0))
F#: KB1.F#, U1.11 (PD5(T1))
G: KB1.G, U1.6 (PD4(XCK/T0))
G#: KB1.G#, U1.5 (PD3(INT1))
GND: B1.-, C2.2, C3.-, C6.-, C7.-, J1.1, J1.2, J2.6 (GND), J3.1, LED3.K (C), R10.A, R11.3 (A), R12.3 (A), S1.3, S1.4, S2.1, S2.2, S3.1, S3.2, SPKR1.-, TOUCH1.2, TOUCH2.2, U1.8 (GND), U1.22 (GND), U2.2 (-IN), U2.4 (V-), X1.P$2 (GND)
MISO: J2.1 (MISO), KB1.C#, U1.18 (PB4(MISO))
MOSI/AUDIO-RIGHT: J2.4 (MOSI), R7.P$1 (1), U1.17 (PB3(MOSI/OC2))
unnamed: C8.-, SPKR1.+
unnamed: U1.9 (PB6(XTAL1/TOSC1)), X1.P$1 (IN)
unnamed: U1.10 (PB7(XTAL2/TOSC2)), X1.P$3 (OUT)
unnamed: C5.1, C7.+, R7.P$2 (2)
unnamed: C8.+, U2.5 (OUT)
unnamed: J3.3, R8.P$2 (2)
unnamed: J3.4, R9.P$2 (2)
unnamed: R10.S, U2.3 (+IN)
unnamed: C5.2, J3.2
unnamed: C4.1, C6.+, R6.P$2 (2)
unnamed: LED1.K (C), R13.P$2 (2)
unnamed: LED2.K (C), R14.P$2 (2)
unnamed: C4.2, J3.5
unnamed: LED3.A, R15.P$2 (2)
unnamed: R8.P$1 (1), R9.P$1 (1), R10.E
RESET*: C1.1, J2.5 (RST), R1.P$1 (1), S1.1, S1.2, U1.1 (PC6(/RESET))
RTS*: C1.2, J1.6
RXD: J1.4, R13.P$1 (1), U1.2 (PD0(RXD))
SCK: J2.3 (SCK), KB1.C, U1.19 (PB5(SCK))
TXD: J1.5, R14.P$1 (1), U1.3 (PD1(TXD))
VCC: B1.+, C2.1, C3.+, J1.3, J2.2 (VCC), LED1.A, LED2.A, R1.P$2 (2), R2.P$2 (2), R3.P$2 (2), R4.P$2 (2), R5.P$2 (2), R11.1 (E), R12.1 (E), R15.P$1 (1), U1.7 (VCC), U1.20 (AVCC), U2.6 (V+)

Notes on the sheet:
Stereo
3xAA
Green
Black
AUDIO L
MOSI / AUDIO R
MISO
SCK
RxD
TxD
knob-adjust
Screwdriver-adjust
4.5V
D10
D11
D12
D13
POWER
RESET
TOUCH1
TOUCH2
STEREO Line Out / Headphone
Mono mix
(Silent when connector in J3)
This work is licensed under the Creative Commons Attribution-ShareAlike 3.0 To view a copy of this license, visit http://creativecommons.org/licenses/by-sa/3.0/
Left
Right

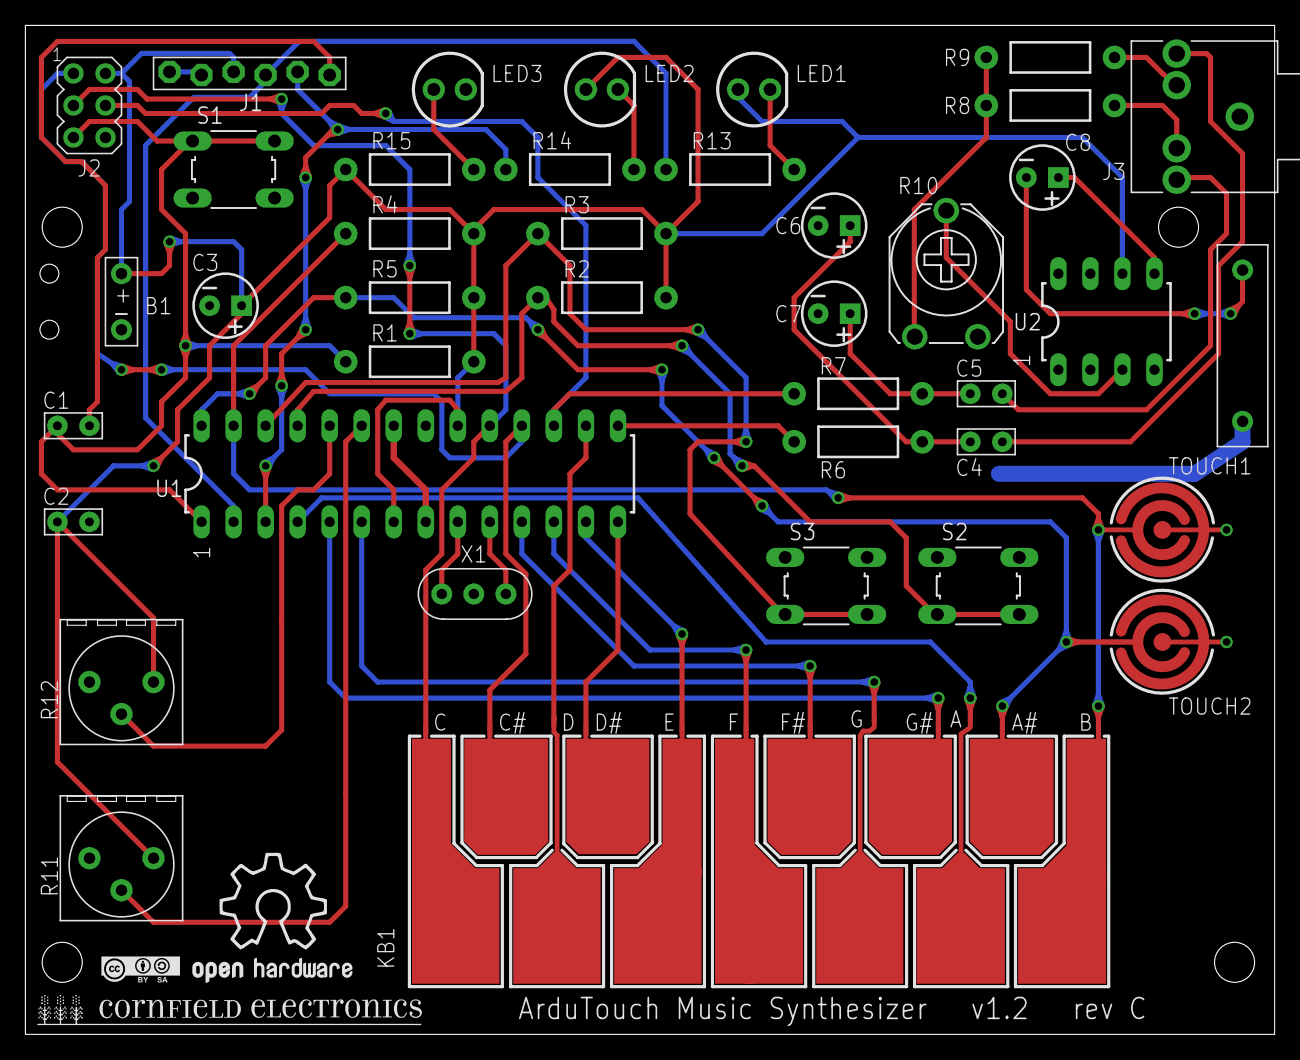
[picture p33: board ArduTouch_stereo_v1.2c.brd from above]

Board: 2 copper layers, 99.1 x 80.0 mm, 43 parts (0 on the bottom side), 39 nets.

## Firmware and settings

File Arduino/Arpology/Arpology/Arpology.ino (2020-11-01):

//
//  Arpology.ino
// 
//  A 4-voice arpeggiating synth, with an auto-improvisation feature.
//
//  How to use:
//
//    1) Press a piano key and Arpolgy will play a 4-voice appegiating pattern
//       based on what note you are pressing.
//
//    2) To shift the keyboard up an octave tap the right button.
//       To shift the keyboard down an octave tap the left button.
//
//    3) Arpology uses two separate U/I "frames." A U/I frame determines 
//       which parameters are controlled by the onboard pots. The two U/I
//       frames for Arpology are:
//
//                1) The Envelope Frame (BLUE LED is on)
//
//                     Top Pot controls envelope attack
//                     Bot Pot controls envelope decay/sustain. 
//
//                2) The Arpeggiator Frame (RED LED is on)
//
//                     Top Pot selects arpeggiation pattern.
//                     Bot Pot controls arpeggiation rate. 
//
//    4) To switch between U/I frames, press the left or right buttons.
//       Pressing the right button selects the Envelope Frame.
//       Pressing the left  button selects the Arpeggiator Frame.
//
//    5) To activate the automatic improvisor double-tap the left button.
//       Arpology now "plays itself." The LED for the current frame will begin
//       flashing, indicating that the auto-improvisor is on. While the auto-
//       improvisor is on, Arpology will not respond to key presses. To turn
//       off the auto-improviser double-tap the left button again.
//      
//    6) There are 10 presets for Arpology. These can be selected by double-
//       tapping the right button and then pressing one of the following keys:
//
//          C  (0)  - turn off all vibrato and panning effects
//          C# (1)  - add vibrato to high voices
//          D  (2)  - use a slow panning effect
//          D# (3)  - use a medium-speed panning effect
//          E  (4)  - use a fast panning effect
//          F  (5)  - play "Ambia", a slow moving improv 
//          F# (6)  - use a major tonality
//          G  (7)  - play "Streaker", a fast moving improv 
//          G# (8)  - use a minor tonality
//          A  (9)  - reset Arpology to its initial state
//
//  Programming Notes:
//
//    1) Arpology is meant to be compiled using the "Stand-alone" runtime model.
//       Otherwise, the LEDs will not operate. This runtime model can be set by
//       uncommenting the "#define __STNDLONE__" statement in Model.h of the 
//       ArduTouch library. 
//
//    2) In version 1.16 of the ArduTouch library an embedded U/I frame was 
//       added to the ArduTouch Control class (a base class for virtually all
//       the objects that make up a synth -- including the synth itself.) The 
//       Arpology synth was written years before version 1.16 of the library
//       was released, and its Envelope and Arpeggiator frames should not be
//       confused with embedded U/I frames, which are disabled by default and 
//       not used in this synth.
//
//
//  Target:   ArduTouch board
// 
//  ---------------------------------------------------------------------------
// 
//  Copyright (C) 2016, Cornfield Electronics, Inc.
// 
//  This work is licensed under the Creative Commons Attribution-ShareAlike 3.0 
//  Unported License.
// 
//  To view a copy of this license, visit
//  http://creativecommons.org/licenses/by-sa/3.0/
// 
//  Created by Bill Alessi & Mitch Altman.
// 
//  ---------------------------------------------------------------------------

#include "ArduTouch.h"                       // use the ArduTouch library 

about_program( Arpology, 1.16 )              // specify sketch name & version

// Specify whether the voices of Arpology can be panned in stereo by 
// uncommenting the following defines

#define ENABLE_PANNING                       // use a panning synth as superclass
#define DUAL_PANNING                         // and superclass = QuadDualPanSynth 
                                             // (otherwise     = QuadPanSynth)

// The following statements insure that presets will work and be accessible
// from the ArduTouch keyboard

#ifndef INTERN_CONSOLE                       
   #error This sketch requires __STNDLONE__ runtime model or higher (Model.h)
#endif

/*----------------------------------------------------------------------------*
 *                                 presets
 *----------------------------------------------------------------------------*/      

define_preset( _, "" )                       // blank preset

define_preset( NoEff, "0g0\\V.``"            // no effects
                     "1g0\\V.``"
                     "2g0\\V.``"
                     "3g0\\V.``"
               #ifdef ENABLE_PANNING
                     "P.`"                
                  #ifdef DUAL_PANNING
                     "X.`"                
                  #endif
               #endif
              )

#ifdef ENABLE_PANNING

define_preset( Pan1, "Pf.5\\<`"              // slow pan
               #ifdef DUAL_PANNING
                     "Xf.2\\<`"
               #endif
              )

define_preset( Pan2, "Pf2\\<`"               // medium-speed pan
               #ifdef DUAL_PANNING
                     "Xf1.2\\<`"
               #endif
              )

define_preset( Pan3, "Pf5.6\\<`"             // fast pan
               #ifdef DUAL_PANNING
                     "Xf1.8\\<`"
               #endif
              )

#endif
                                             // vibrato
define_preset( Vib, "2V+<t5\\d64\\``"
                    "3V+<f4.5\\t10\\d80\\``"
              )

define_preset( Ambia, "!a120\\d100\\N6\\r33\\U"
                      "2V<-f3.6\\d48\\t9\\``"
                      "3V<-f4.15\\d48\\t15\\``"
                  #ifdef ENABLE_PANNING
                      "Pf.7\\d128\\<`"
                    #ifdef DUAL_PANNING
                      "Xf.4\\d128\\<`"
                    #endif
                  #endif
              )

define_preset( Streaker, "!-a9\\d55\\N7\\r213\\U"
                         "2g100\\V<f6\\d48\\t6\\``"
                  #ifdef ENABLE_PANNING
                         "Pf3\\d128\\<`"
                     #ifdef DUAL_PANNING
                         "Xf1.5\\d128\\<`"
                     #endif
                  #endif
              )

define_preset( Maj, "+" )                    // select Major tonality
define_preset( Min, "-" )                    // select Minor tonality
define_preset( Reset, "!" )                  // reset synth


begin_bank( myPresets )                      // these presets will be loaded

   _preset( NoEff )
   _preset( Vib )

#ifdef ENABLE_PANNING
   _preset( Pan1 )
   _preset( Pan2 )
   _preset( Pan3 )
#else
   _preset( _ )
   _preset( _ )
   _preset( _ )
#endif

   _preset( Ambia )
   _preset( Maj )
   _preset( Streaker )
   _preset( Min )
   _preset( Reset )

end_bank()
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

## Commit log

2016-05-05 ArduTouch assembly instructions
    Initial version of assembly instructions. Mostly just photos, for now.
2016-05-07 ArduTouch schematic
    exported from Eagle
2016-05-07 ArduTouch BOM
    ArduTouch Bill of Materials
    [ArduTouch_BOM.csv]
2016-07-10 update to PCB v1.2 rev C & DuoPoly v2.05
2016-12-25 Update to latest PCB, Eagle library parts, Arduino sketches, ArduTouch Arduino Libary, Quick Reference Guide
    V1.2 rev B PCB & Schematic
    ArduTouch Arduino Library v0.63
    DuoPoly V2.23
    Thick V0.38
    Arpology V0.62
    Quick Reference Guide V2.16
2017-04-23 Update to Rev C PCB, ArduTouch Arduino library v0.86, DuoPoly synth sketch v2.27, Thick synth sketch v0.56, Arpology synth sketch v0.96
    [ArduTouch_BOM.csv, ArduTouch_stereo_v1.2.brd, ArduTouch_stereo_v1.2.sch]
2017-11-21 Update to v1.02 of ArduTouch firmware sketches
    ArduTouch Arduino librarie is now very real.
    New example synthesizer sketches in Arduino library.
    Latest versions of synths: DuoPoly, Arpology, and Thick.
    New synth: Beatitude (drum machine).
    [ArduTouch_stereo_v1.2c.brd, ArduTouch_stereo_v1.2c.sch]
2017-12-16 Update Assembly Instructions, add Programming Guide
    Assembly Instructions now include how to re-program that ArduTouch.
    Added Programming Guide as a separate document.
2018-03-28 Beatitude allows the user to play bass live over the drum sequences, compiles with latest version (V1.8.5) of Arduino IDE
    1) The new version of Beatitude allows the user to play bass live over
    the drum sequences -- i.e. when a drum sequence is being played back by
    the ArduTouch (the red LED is flashing) then the keyboard becomes a bass
    sound that can be played spontaneously over the drum track.
    2) The library now provides "lofi" versions of all the drum samples. The
    example sketch _30_DrumPad.ino contains a discussion of these.
    3) Sawtooth and square wave oscillators have been added in a new
    library module WaveGen. The waveforms they generate are computed on the
    fly, they are not wave-tab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
    [Arpology.ino, Beatitude.ino, DuoPoly.ino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]
2018-04-07 New Mantra synth; Library has several new base classes
    New Mantra synthesizer, which plays a few layers of Indian-like drone
    music (choice of two drones), with an exotic scale you can play on top
    of it, with an inability to make any music that doesn't sound good. :)
    The library now includes several new base classes, among which are:
    FiltEnv - a dynamic (i.e. enveloped) low-pass filter
    DelayVibrato - adds a delay time before triggering stock vibrato
    DualOsc - allows for the transparent pairing of any two
    oscillators.
    Additionally, the old Sequencer class has been re-written, and is now
    abstract in that it
    doesn't know where the compiled sequence is even stored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
    [Beatitude.ino, DuoPoly.ino, Mantra.ino]
2018-08-26 updated ArduTouch Arduino library
    new features for effects and sound dynamics, bug fix, new examples for
    tutorials on how to make your own synth sketches
    [Arpology.ino, Beatitude.ino, DuoPoly.ino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]
2018-12-22 Make compatible with Kitspace (#6)
    Changes for making the ArduTouch project compatible with Kitspace.org:
    * Make BOM compatible with Kitspace
    * Plot gerbers for v1.2c, include unzipped files
    * Add more Mouser part selections/alternatives
    * Add kitspace.yaml manifest file
    [ArduTouch_BOM.csv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]
2018-12-22 PLEASE USE ARDUINO V1.66 -- New Arduino Library with added features, new ZapShot synth
    ArduTouch Arduino Library v1.09:
    add QuantumOsc module
    add VirtualPot module
    add the virtual method Osc::realFreq()
    Osc::charEv( chrInfo ) displays real, not effective, frequency
    Voice::Voice() sets osc to NULL
    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
2019-02-28 Works with latest Arduino V1.8.8, new sample for drums, added classes, 2 more tutorial examples
    What's New in ArduTouch Release Version 1.10
    --------------------------
    1) The ArduTouch library now works with the latest release of the
    Arduino IDE
    (1.8.8).
    There is a known bug -- recently introduced -- in the Arduino linker,
    that
    causes an error if a class method is given the same name as a global
    function.
    In order to circumvent this bug, the method Synth::setup() has been
    renamed
    Synth::config(). (Thanks to Charles Shapiro for suggesting this fix.)
    Also, VoxSynth::setupVoices() has been renamed VoxSynth::configVoices()
    to keep the naming conventions consistent.
    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
    [Arpology.ino, Beatitude.ino, DuoPoly.ino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]
2019-05-23 New Dronetic synth, added Harmonic Tuning class, added Gain effect
    1) A new synth, Dronetic.ino, is available.
    Dronetic uses 2 drones, each drone is made up of 4 quantum square wave
    oscillators, and the drones are panned dynamically in stereo. You can
    then play a lead over the drones, and the pots control a bunch of
    parameters in real time as you play.
    For an audio demo of Dronetic go to https://www.youtube.com/c/mitchaltman23
    2) A HarmonicTuning class has been added to the library, as an alternative
    to EqualTemperament.
    For a discussion of Harmonic Tuning and an example of how to override
    the system default tuning of EqualTemperament see Dronetic.ino.
    3) A Gain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
    [Dronetic.ino, Xoid.ino]
2019-10-11 new Quadrant synth, new Envelope classes
    What's New in Version 1.12
    Works fine with the latest (to date) Arduoino software v1.8.10
    1) A new synth, Quadrant, is released.
    Quadrant features a hybrid stereo effect called an Echotron, which is part
    echo, part arpeggiator, and part pitch shifter.
    For audio demos of Quadrant go to https://www.youtube.com/c/mitchaltman23
    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
2019-12-02 bug fixes in Beatitude and Mantra, updated Quadrant, LFO internals re-written, rearranged tutorial examples in Arduino library, 2 new examples
    What's New in Version 1.13
    1) LFO internals have been rewritten to use fixed-point 16 bit math instead
    of floating point math, significantly reducing the code footprint.
    There are now four different LFO waveforms available (triangle, square,
    rising sawtooth and falling sawtooth) instead of just one (triangle).
    As part of the LFO rewrite, the following method:
    LFO::setDepth( double x ) -- where x is between 0.0 and 1.0
    has been changed to
    LFO::setDepth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
    [Arpology.ino, Beatitude.ino, Dronetic.ino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]
2020-01-22 Updated Beatitude, bug fixes in RealTimeSequencer in library, new demo video
    === RELEASE 1.14 ===
    This release is all about Beatitude and the RealTimeSequencer class in the library.
    The new version of Beatitude has these added features:
    1. The drum kit is now panned in stereo.
    2. The top pot controls the balance between the drum kit and the bass.
    3. When recording a sequence with prior versions of Beatitude the 1st
    drum hit was often missed if it happened "right before" the 1st beat
    of the 1st measure. This has been fixed.
    4. Fixed problems with sequence playback via changes to the RealTimeSequencer
    class in the library (see below).
    RealTimeSequencer::jif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
    [Beatitude.ino]
2020-11-01 Update ArduTouchAssembly.pdf
    Update to Assembly Instructions: Better details for section on how to solder
2020-11-01 Definitive version of the library for a standalone ArduTouch card, plus Hocus synth
    This V1.16 release is the definitive version of the library for a standalone ArduTouch card. V1.16 sets the stage for release V1.17, which will (hopefully) implement a MIDI interface via the host.
    What's New in Version 1.16
    -----------------------------------------
    Make sure that the PCB REV of your board (printed near the bottom of the
    ArduTouch card) corresponds to the revision declared in System.h
    0) New Hocus synth
    1) ADSR internals have been rewritten to use fixed-point 16 bit math instead
    of floating point math, significantly reducing the code foo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
    [Arpology.ino, Beatitude.ino, Dronetic.ino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]

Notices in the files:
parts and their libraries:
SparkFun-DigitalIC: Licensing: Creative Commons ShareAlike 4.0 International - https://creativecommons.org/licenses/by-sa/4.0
